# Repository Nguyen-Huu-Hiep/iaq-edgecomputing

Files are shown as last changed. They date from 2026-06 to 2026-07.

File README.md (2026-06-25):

# Hệ Thống Giám Sát Chất Lượng Không Khí Trong Nhà Dựa Trên Edge Computing

## Tổng Quan

Đề tài xây dựng hệ thống giám sát chất lượng không khí trong nhà (Indoor Air Quality - IAQ) dựa trên công nghệ Edge Computing và Internet of Things (IoT). Hệ thống sử dụng vi điều khiển ESP32 kết hợp với nhiều cảm biến môi trường để thu thập, xử lý và giám sát các thông số chất lượng không khí theo thời gian thực.

Khác với các hệ thống IoT truyền thống phụ thuộc hoàn toàn vào điện toán đám mây, hệ thống này thực hiện phần lớn quá trình xử lý dữ liệu ngay trên thiết bị biên (Edge Device). Các dữ liệu từ cảm biến được lọc nhiễu, phân tích và tính toán chỉ số chất lượng không khí (AQI) trước khi được gửi lên máy chủ để lưu trữ và trực quan hóa.

Hệ thống có khả năng giám sát liên tục các thông số như bụi mịn PM2.5, PM10, nồng độ CO₂, TVOC, nhiệt độ và độ ẩm. Chỉ số AQI được tính toán trực tiếp trên ESP32 theo tiêu chuẩn US EPA, giúp giảm độ trễ và đảm bảo khả năng cảnh báo kịp thời khi chất lượng không khí suy giảm.

---

## Chức Năng Chính

- Giám sát chất lượng không khí theo thời gian thực
- Đo nồng độ bụi PM2.5 và PM10
- Đo nồng độ khí CO₂
- Đo chỉ số TVOC
- Đo nhiệt độ và độ ẩm môi trường
- Tính toán chỉ số AQI tại thiết bị Edge
- Hiển thị dữ liệu trên màn hình TFT
- Lọc nhiễu bằng Median Filter và Kalman Filter
- Kết nối WiFi và tự động kết nối lại khi mất mạng
- Đồng bộ dữ liệu lên nền tảng Supabase
- Hỗ trợ cập nhật firmware OTA (Over-The-Air)
- Cảnh báo cục bộ khi chất lượng không khí vượt ngưỡng
- Cấu hình hệ thống thông qua giao diện Web

---

## Kiến Trúc Hệ Thống



## Phần Cứng Sử Dụng

- ESP32 Development Board
- Cảm biến bụi PMS5003/PMS7003
- Cảm biến CO₂ Sensirion SCD4x
- Cảm biến TVOC CCS811
- Màn hình TFT ST7789
- Hệ thống mạng WiFi

---

## Mô Hình Edge Computing

Hệ thống được thiết kế theo kiến trúc Edge Computing, trong đó ESP32 đóng vai trò là nút xử lý biên (Edge Node).

Các tác vụ được thực hiện trực tiếp trên ESP32 bao gồm:

- Thu thập dữ liệu cảm biến
- Kiểm tra tính hợp lệ của dữ liệu
- Lọc nhiễu tín hiệu
- Tính toán AQI
- Phát hiện trạng thái bất thường
- Kích hoạt cảnh báo cục bộ

Nhờ đó hệ thống mang lại các lợi ích:

- Giảm độ trễ xử lý
- Giảm lưu lượng truyền dữ liệu lên Cloud
- Giảm tải cho máy chủ
- Tăng tính ổn định khi mất kết nối Internet
- Đảm bảo khả năng cảnh báo theo thời gian thực

---

## Xử Lý Dữ Liệu

### Median Filter

Được sử dụng để loại bỏ các giá trị nhiễu đột biến từ cảm biến.

### Kalman Filter

Được sử dụng để làm mượt dữ liệu đo, tăng độ ổn định và độ tin cậy của kết quả.

### Tính Toán AQI

Chỉ số chất lượng không khí AQI được tính toán trực tiếp trên ESP32 dựa trên nồng độ PM2.5 theo tiêu chuẩn của Cơ quan Bảo vệ Môi trường Hoa Kỳ (US EPA).

---

## Kết Nối Đám Mây

Dữ liệu sau khi được xử lý tại Edge sẽ được gửi lên nền tảng Supabase thông qua giao thức HTTPS để:

- Lưu trữ lịch sử dữ liệu
- Phân tích xu hướng chất lượng không khí
- Hiển thị trên Dashboard giám sát
- Hỗ trợ truy cập từ xa

---

## Ứng Dụng

Hệ thống có thể được triển khai tại:

- Nhà ở thông minh (Smart Home)
- Lớp học
- Văn phòng
- Phòng thí nghiệm
- Bệnh viện
- Nhà xưởng sản xuất
- Các không gian kín cần giám sát chất lượng không khí

---

## Công Nghệ Sử Dụng

- ESP32
- Edge Computing
- Internet of Things (IoT)
- Supabase
- WiFi Manager
- OTA Firmware Update
- HTTP/HTTPS Communication
- AQI Calculation (US EPA Standard)

---

## Tác Giả

**Nguyễn Hữu Hiệp**

Ngành Kỹ thuật Tin học Công nghiệp

**Đồ án tốt nghiệp: Hệ thống giám sát chất lượng không khí trong nhà dựa trên Edge Computing và IoT**

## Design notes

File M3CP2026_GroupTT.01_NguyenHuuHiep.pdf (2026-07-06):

CAPSTONE PROJECT · CLASS 21PFIVEV2 · FAST – DUT

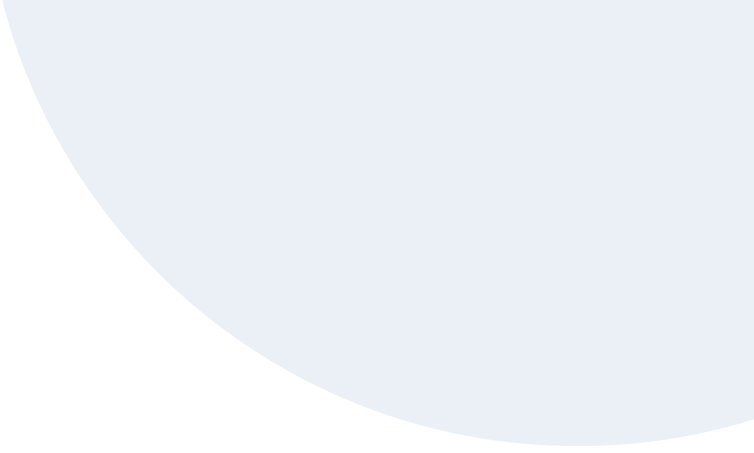
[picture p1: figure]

# DESIGN AND IMPLEMENTATION OF AN IOT-BASED INDOOR AIR QUALITY MONITORING SYSTEM FOR EDUCATIONAL ENVIRONMENTS

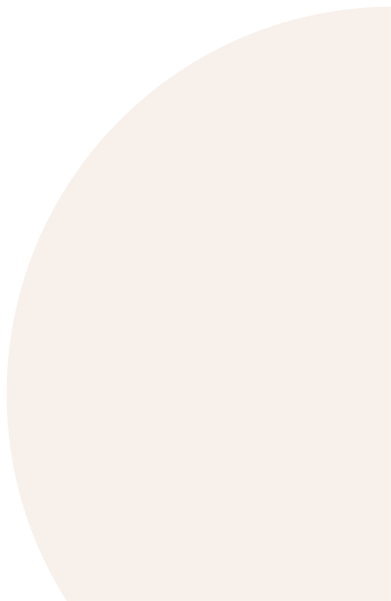
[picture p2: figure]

Students Tran Duong Xuan Anh · Nguyen Huu Hiep · Nguyen Minh Ngoc Huy

Supervisor Dr. Nguyen Le Hoa

Da Nang, June 2026

### AGENDA

# What We'll Cover

Experimental Results & Evaluation | 05 Conclusion & Future Directions

### 01 RESEARCH OVERVIEW

# Why is it necessary to monitor air quality in classrooms?

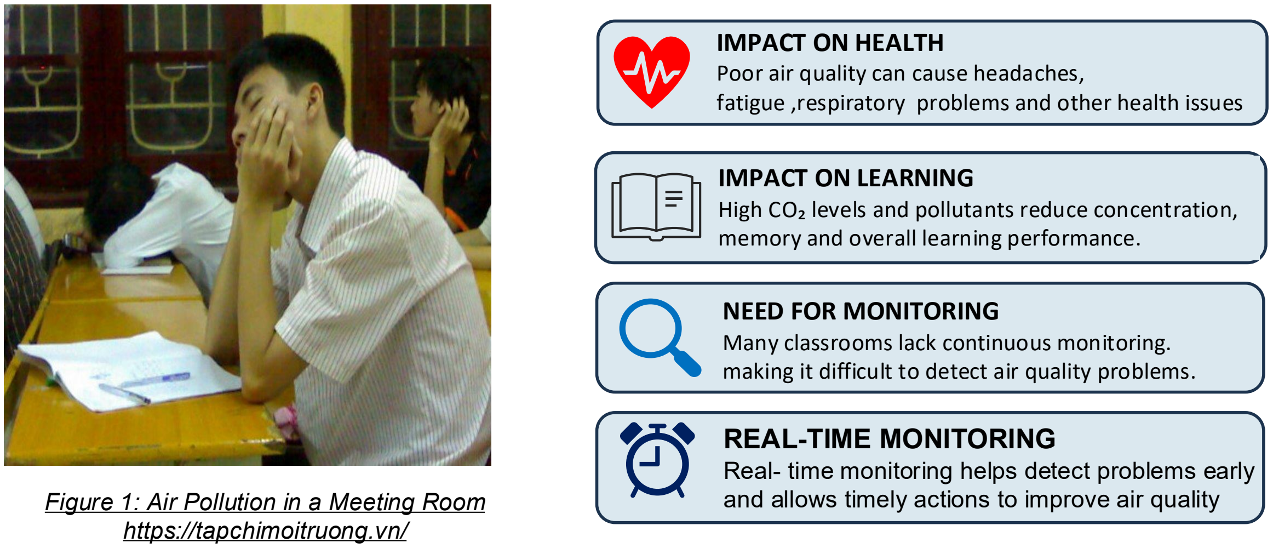
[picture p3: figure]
https://tapchimoitruong.vn/; REAL-TIME MONITORING; IMPACT ON HEALTH Poor air quality can cause headaches,; IMPACT ON LEARNING; memory and overall learning performance.; NEED FOR MONITORING Many classrooms lack continuous monitoring.

Figure 1: Air Pollution in a Meeting Room

Real- time monitoring helps detect problems early and allows timely actions to improve air quality fatigue ,respiratory problems and other health issues

High CO₂ levels and pollutants reduce concentration,

making it difficult to detect air quality problems.

### 01 RESEARCH OVERVIEW

## Research Objectives

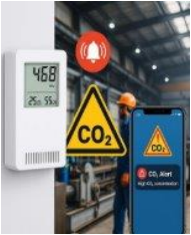
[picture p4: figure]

References [1] PM Decision 538/QĐ-TTg, 2021. [2] EVN Annual Report, 2023. [31] EVN Regulation 6074/EVN-KD, 2024. | 4 / 24

### Design a smart air quality monitoring system for classrooms

### Real-time IAQ monitoring

### Early warning when CO₂ and PM2.5 exceed safety thresholds

### Provide data for trend analysis

### All collected data are uploaded to a cloud dashboard

### Support classroom environment management

### Increase awareness among students and teachers

Figure 2: Threshold Exceedance Warning (https://ubibot.vn/wp-content/uploads/2025/06/thiet-bi-canh-bao-nong-do-co2.jpg)

### 01 RESEARCH OVERVIEW

# Overview of indoor air quality in classrooms

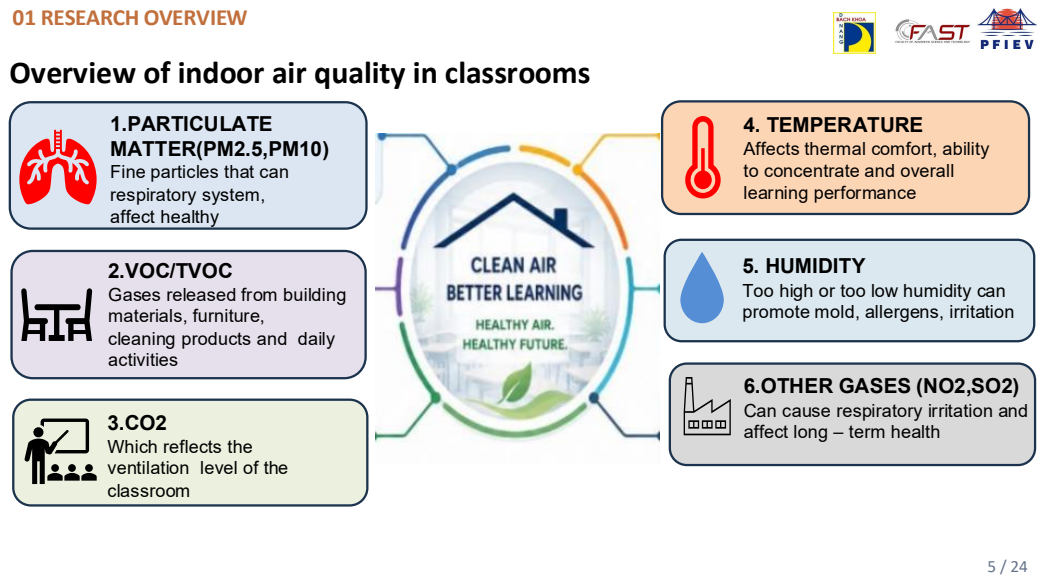
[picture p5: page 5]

1.PARTICULATE
MATTER(PM2.5,PM10)
Fine particles that can
respiratory system,
affect healthy

4. TEMPERATURE
Affects thermal comfort, ability
to concentrate and overall
learning performance

2.VOC/TVOC
Gases released from building
materials, furniture,
cleaning products and daily
activities

5. HUMIDITY
Too high or too low humidity can
promote mold, allergens, irritation

6.OTHER GASES (NO2,SO2)
Can cause respiratory irritation and
affect long – term health

Which reflects the
ventilation level of the
classroom

### 01 RESEARCH OVERVIEW

# Commercial product

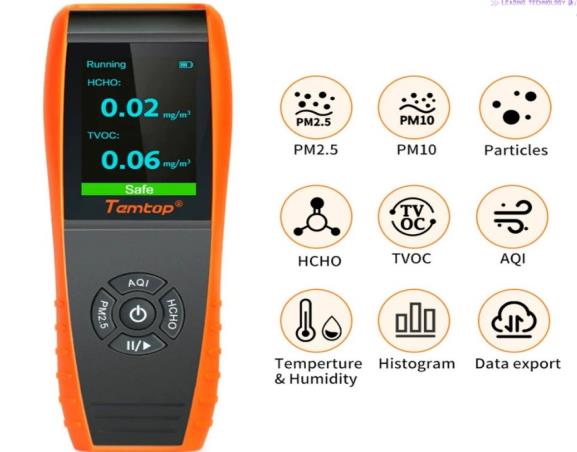
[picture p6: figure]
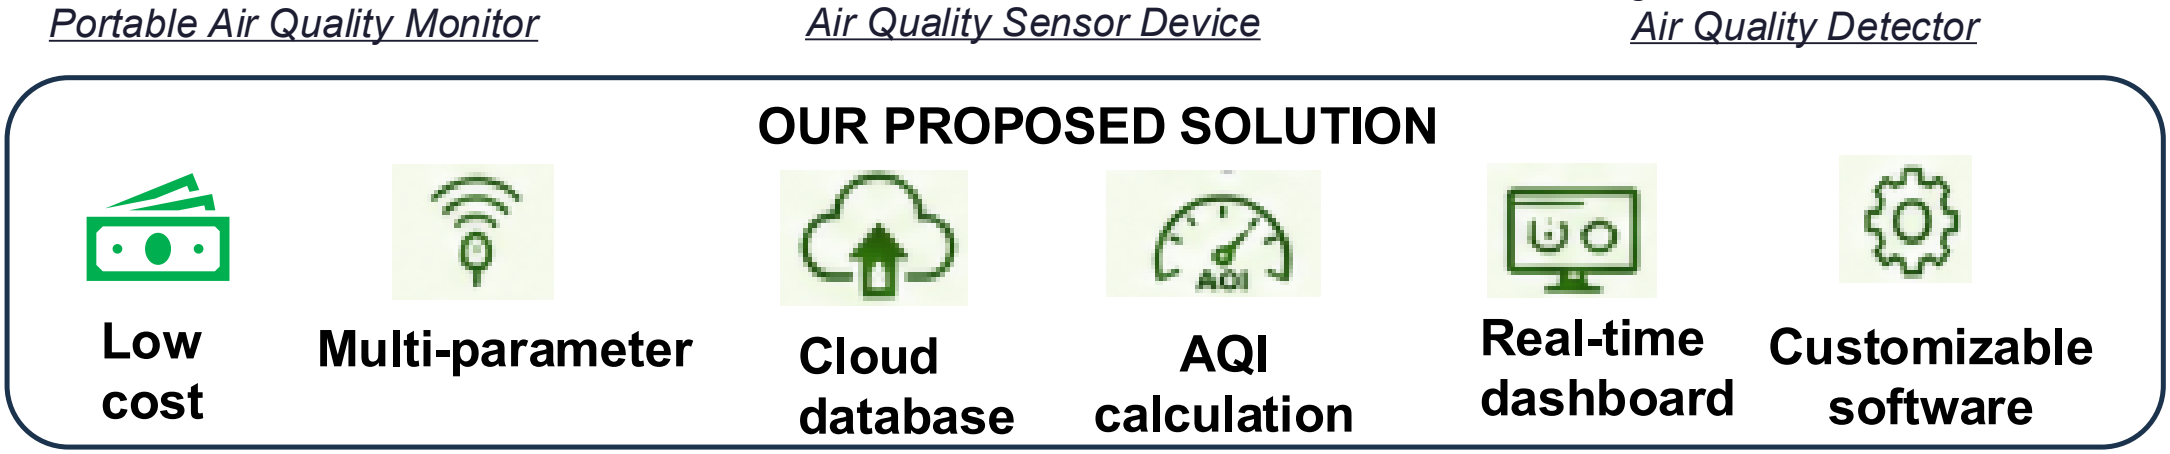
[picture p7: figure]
Portable Air Quality Monitor; Air Quality Sensor Device; Air Quality Detector; OUR PROPOSED SOLUTION; Low cost; Multi-parameter; AQI; calculation; Real-time dashboard; Customizable software; Cloud database

Figure (https://dientuthaithang.com/may-do-chat-luong-khong-khi-7-in-1-temtop-lkc-1000s-3161-357.html) 3 (https://dientuthaithang.com/may-do-chat-luong-khong-khi-7-in-1-temtop-lkc-1000s-3161-357.html): Temtop LKC (https://dientuthaithang.com/may-do-chat-luong-khong-khi-7-in-1-temtop-lkc-1000s-3161-357.html)- (https://dientuthaithang.com/may-do-chat-luong-khong-khi-7-in-1-temtop-lkc-1000s-3161-357.html)1000 (https://dientuthaithang.com/may-do-chat-luong-khong-khi-7-in-1-temtop-lkc-1000s-3161-357.html)S

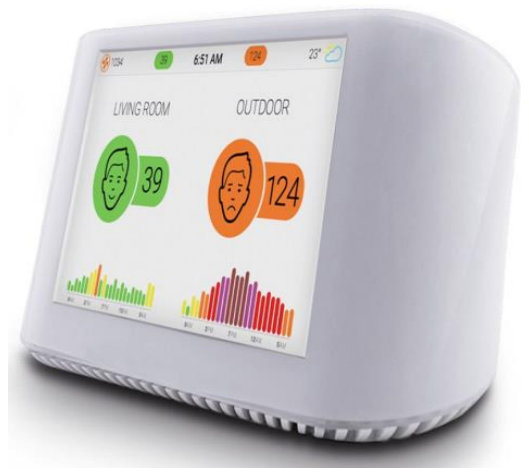
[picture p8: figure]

Figure (https://www.iqair.com/vi/products/air-quality-monitors/airvisual-pro-indoor-monitor) 4 (https://www.iqair.com/vi/products/air-quality-monitors/airvisual-pro-indoor-monitor): IQAir AirVisual Pro

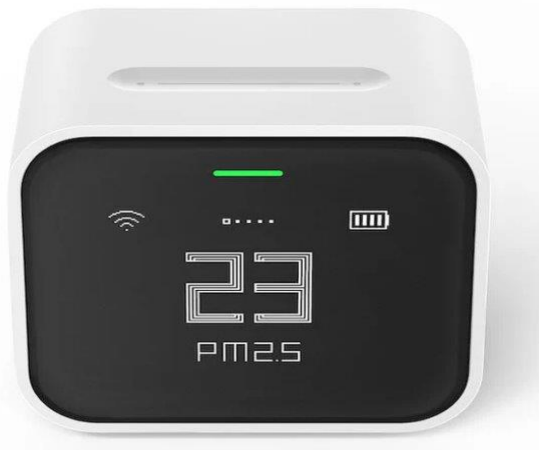
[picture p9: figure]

Figure (https://miworld.vn/thiet-bi-cho-suc-khoe/may-do-chat-luong-khong-khi-xiaomi-pm2-5-air-quality-detector-p11700.html) 5 (https://miworld.vn/thiet-bi-cho-suc-khoe/may-do-chat-luong-khong-khi-xiaomi-pm2-5-air-quality-detector-p11700.html): Xiaomi PM2.5

### 2.THEORETICAL BASIS AND STANDARDS

## General Introduction to Air Quality Standards

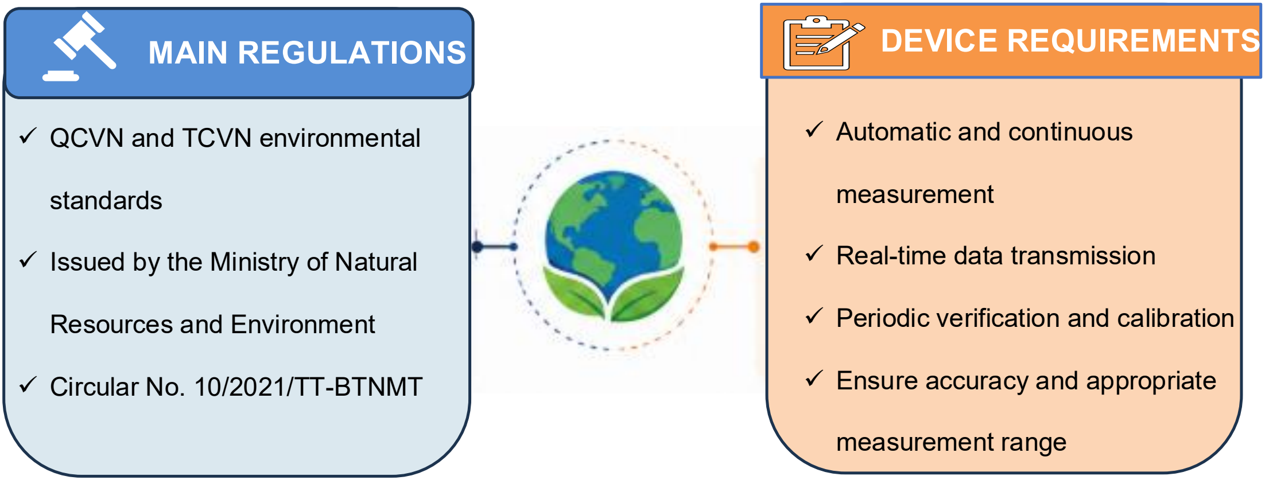
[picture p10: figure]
MAIN REGULATIONS; ✓ QCVN and TCVN environmental; standards; ✓ Issued by the Ministry of Natural; Resources and Environment; ✓ Circular No. 10/2021/TT-BTNMT; DEVICE REQUIREMENTS; ✓ Automatic and continuous; measurement; ✓ Real-time data transmission; ✓ Periodic verification and calibration; ✓ Ensure accuracy and appropriate; measurement range

### 2.THEORETICAL BASIS AND STANDARDS

## Pollution Level Classification According to IAQ

IAQ Range | Pollution Level | Display Color | Health Impact
0 – 50 | Good | Green | No health effects
51 – 100 | Moderate | Yellow | May cause minor effects for sensitive individuals
101 – 150 | Unhealthy for Sensitive Groups | Orange | Affects sensitive groups(elderly, children)
151 – 200 | Unhealthy | Red | Affects everyone’s health
201 – 300 | Very Unhealthy | Purple | Serious health effects
> 300 | Hazardous | Maroon | Emergency health warning

Table 2: Air Quality Assessment Levels

### 2.THEORETICAL BASIS AND STANDARDS

# Technical specification requirements

Table 3: Required Technical Specifications for Measured Parameters

No | Measurement Parameter | Unit | Accuracy(% of range) | Measurement Range | Resolution | Response Time
1 | Temperature | °C | ±5% | 0 ÷ 80 | 0,1 | ≤ 120 seconds
2 | PM2.5 dust | µg/m³ | ±5% | 0 ÷ 250 | 0,1 | ≤ 60 seconds
3 | PM10 dust | µg/m³ | ±3% | 0 ÷ 500 | 0.1 | ≤ 60 seconds
4 | CO2 | ppm | ±5% | 0 ÷ 5.000 | 1 | ≤ 120 seconds
5 | TVOC | µg/m³ | ±10% | 0 ÷ 2.000 | 1 | ≤ 60 seconds

Ensures accuracy and
reliability of measurement

Meets national standards
for IAQ monitoring

Real-time response for
timely alerts and actions

### 03 · SYSTEM DESIGN

# Overall System Architecture

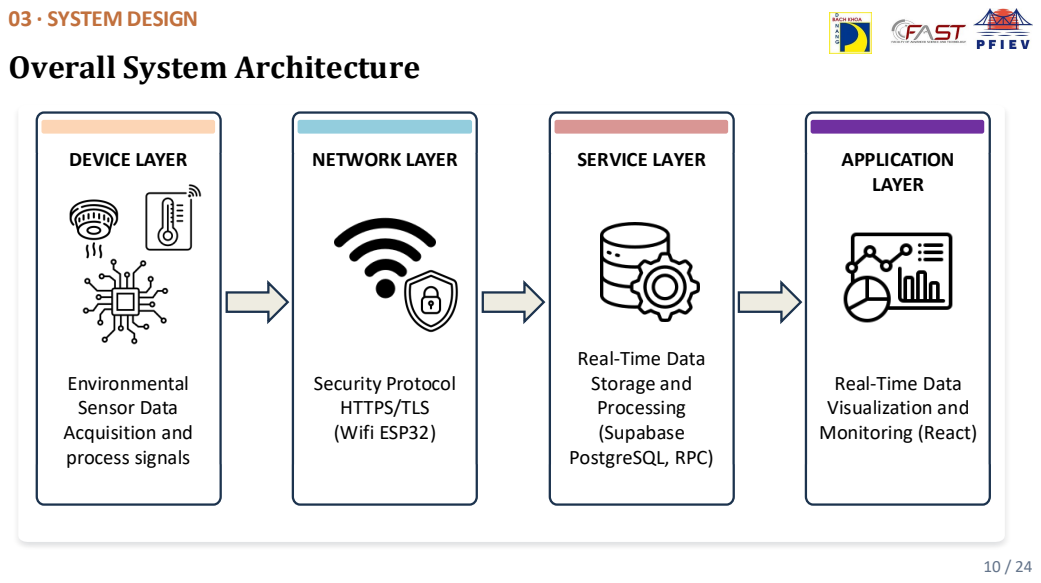
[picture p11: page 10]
DEVICE LAYER; Environmental Sensor Data Acquisition and process signals; NETWORK LAYER; Security Protocol HTTPS/TLS (Wifi ESP32); SERVICE LAYER; APPLICATION LAYER

Real-Time Data
Storage and
Processing
(Supabase
PostgreSQL, RPC)

Visualization and
Monitoring (React)

### 03 · SYSTEM DESIGN

# Hardware Block Diagram & Circuit Schematic

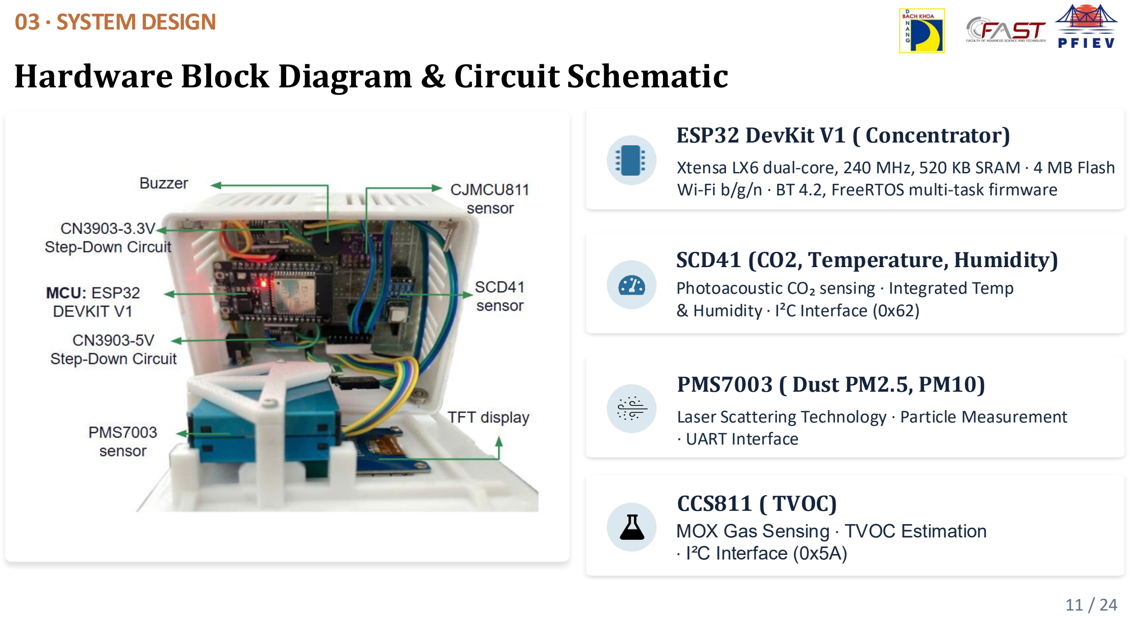
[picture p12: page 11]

ESP32 DevKit V1 ( Concentrator)

Xtensa LX6 dual-core, 240 MHz, 520 KB SRAM · 4 MB Flash Wi-Fi b/g/n · BT 4.2, FreeRTOS multi-task firmware

SCD41 (CO2, Temperature, Humidity)

PMS7003 ( Dust PM2.5, PM10)

CCS811 ( TVOC)

Photoacoustic CO₂ sensing · Integrated Temp
& Humidity · I²C Interface (0x62)

Laser Scattering Technology · Particle Measurement
- UART Interface

MOX Gas Sensing · TVOC Estimation
- I²C Interface (0x5A)

### 03 · SYSTEM DESIGN

# Multitasking with FreeRTOS on a Dual-Core Architecture

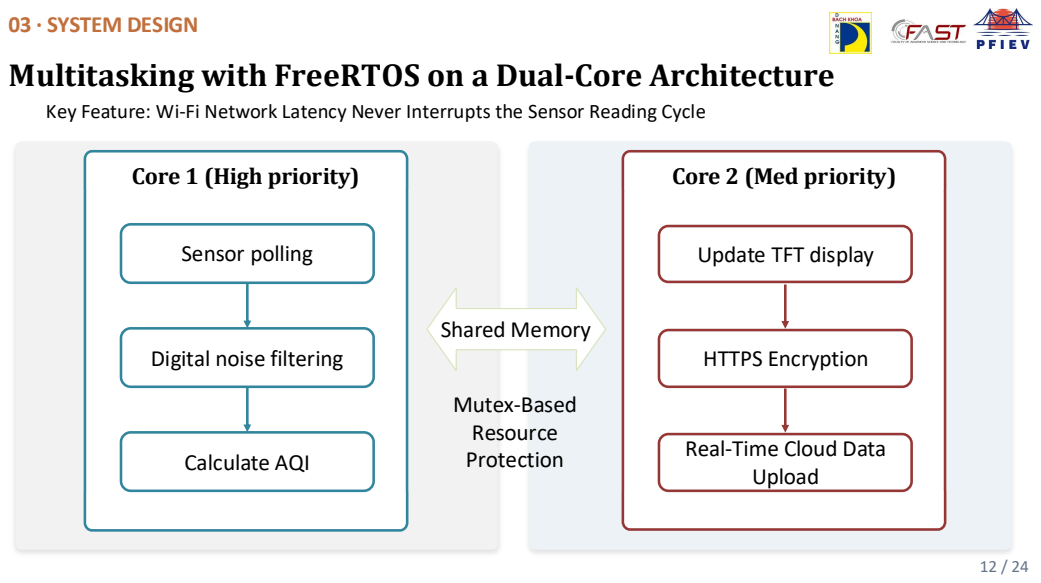
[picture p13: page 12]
Sensor polling; Calculate AQI; HTTPS Encryption; Shared Memory; Mutex-Based Resource Protection

Key Feature: Wi-Fi Network Latency Never Interrupts the Sensor Reading Cycle

Core 1 (High priority)

Core 2 (Med priority)

Update TFT display

Digital noise filtering

Real-Time Cloud Data
Upload

### 03 · SYSTEM DESIGN

# Signal Processing Pipeline

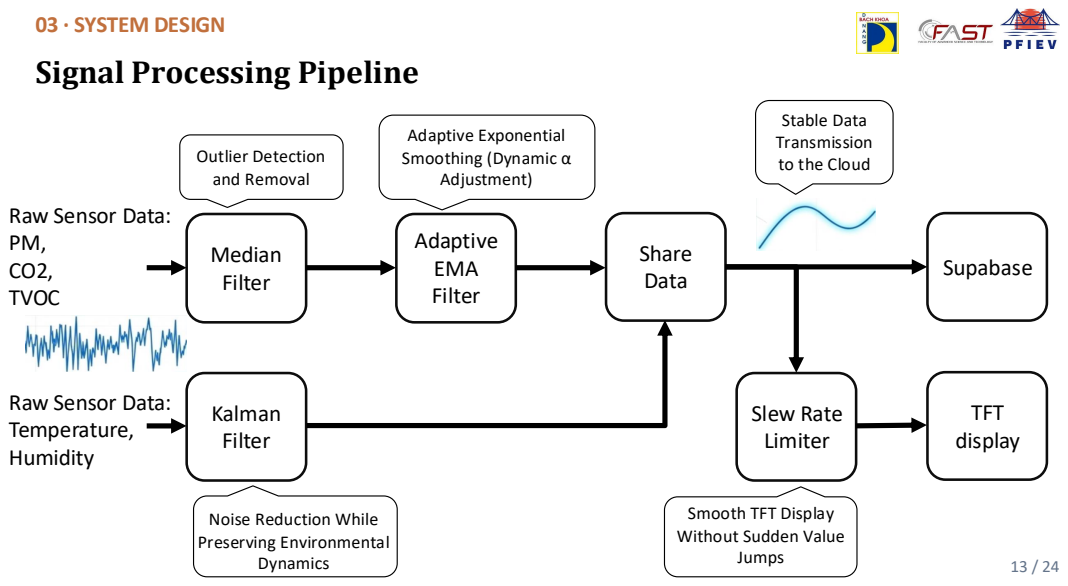
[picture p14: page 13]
Median Filter; Kalman Filter; Adaptive EMA Filter; Share; Data; Supabase; Slew Rate Limiter; TFT display; Raw Sensor Data: PM, CO2, TVOC; Adaptive Exponential Smoothing (Dynamic α Adjustment); Outlier Detection and Removal; Dynamics; Jumps

Stable Data
Transmission
to the Cloud

Raw Sensor Data:
Temperature,
Humidity

Noise Reduction While
Preserving Environmental

Smooth TFT Display
Without Sudden Value

### 03 · SYSTEM DESIGN

# Cloud Storage Architecture (Supabase/PostgreSQL)

### JSON Payload from the Edge Device (Edge Payload)

### RPC Stored Procedure (upsert_iaq)

### Table aqi_room

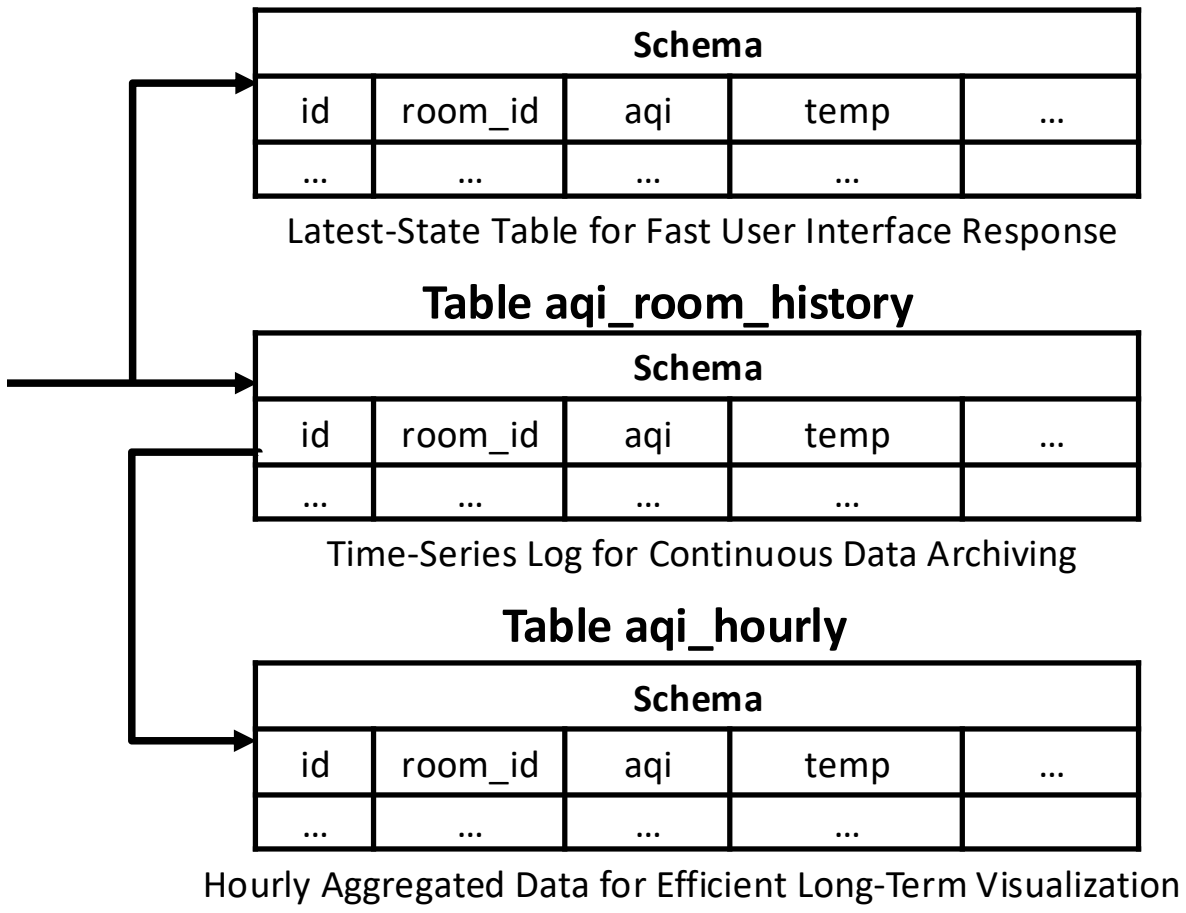
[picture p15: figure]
Table aqi_room_history; Table aqi_hourly; Schema; room_id; aqi; temp

Latest-State Table for Fast User Interface Response

Time-Series Log for Continuous Data Archiving

Hourly Aggregated Data for Efficient Long-Term Visualization

Atomic Operations at the
Database Layer to Eliminate Network Bottlenecks

### 03 · SYSTEM DESIGN

# Web Monitoring Interface

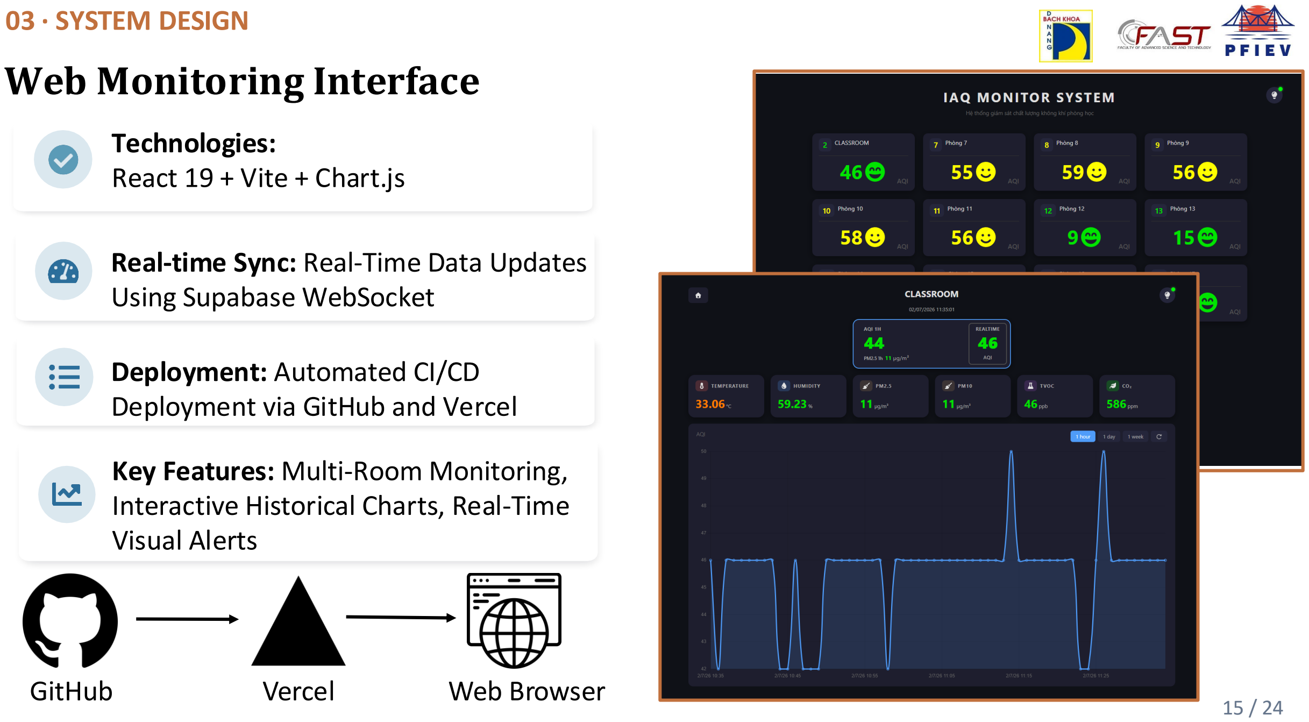
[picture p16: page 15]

### Technologies: React 19 + Vite + Chart.js

### Real-time Sync: Real-Time Data Updates Using Supabase WebSocket

### Deployment: Automated CI/CD Deployment via GitHub and Vercel

Key Features: Multi-Room Monitoring,

### Interactive Historical Charts, Real-Time Visual Alerts

GitHub | Vercel | Web Browser

### 03 · SYSTEM DESIGN

# Wi-Fi Captive Portal & update OTA

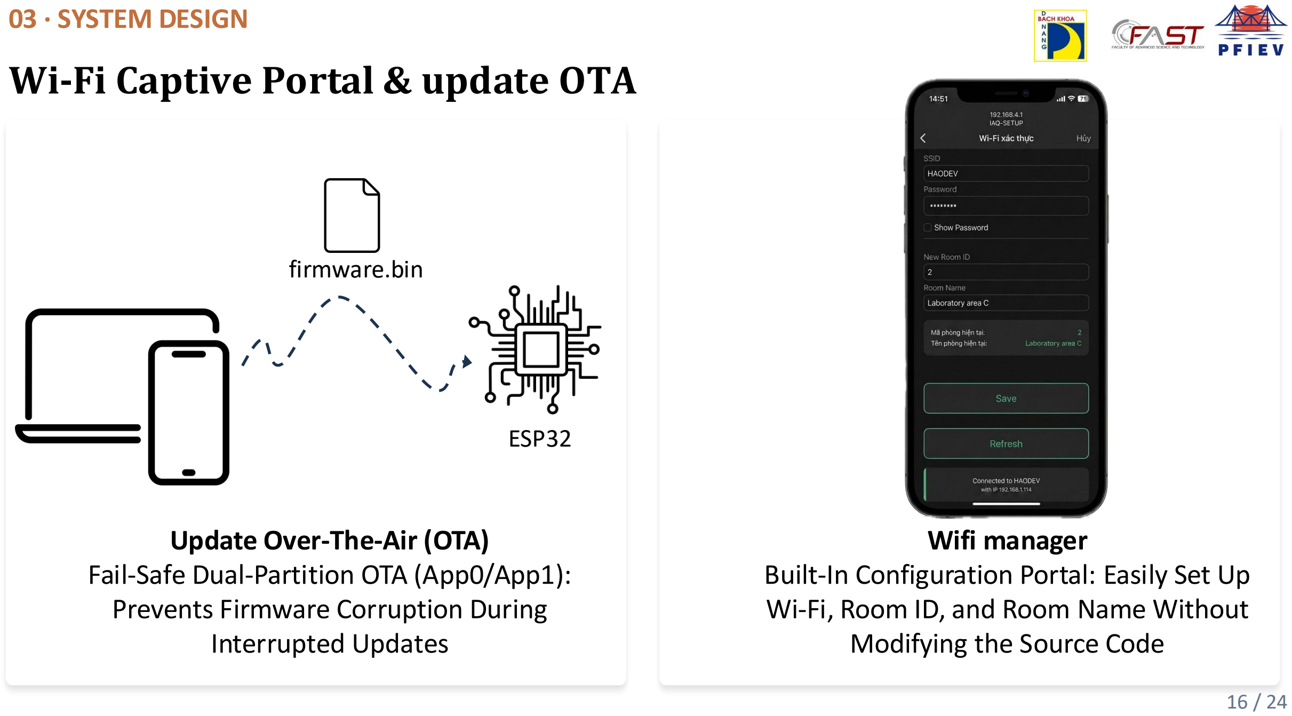
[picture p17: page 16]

### Wifi manager Built-In Configuration Portal: Easily Set Up Wi-Fi, Room ID, and Room Name Without Modifying the Source Code

firmware.bin

ESP32

### Update Over-The-Air (OTA) Fail-Safe Dual-Partition OTA (App0/App1): Prevents Firmware Corruption During Interrupted Updates

### 4 · EXPERIMENTATION AND EVALUATION OF SYSTEM RESULTS

# Experimental Environment and Configuration

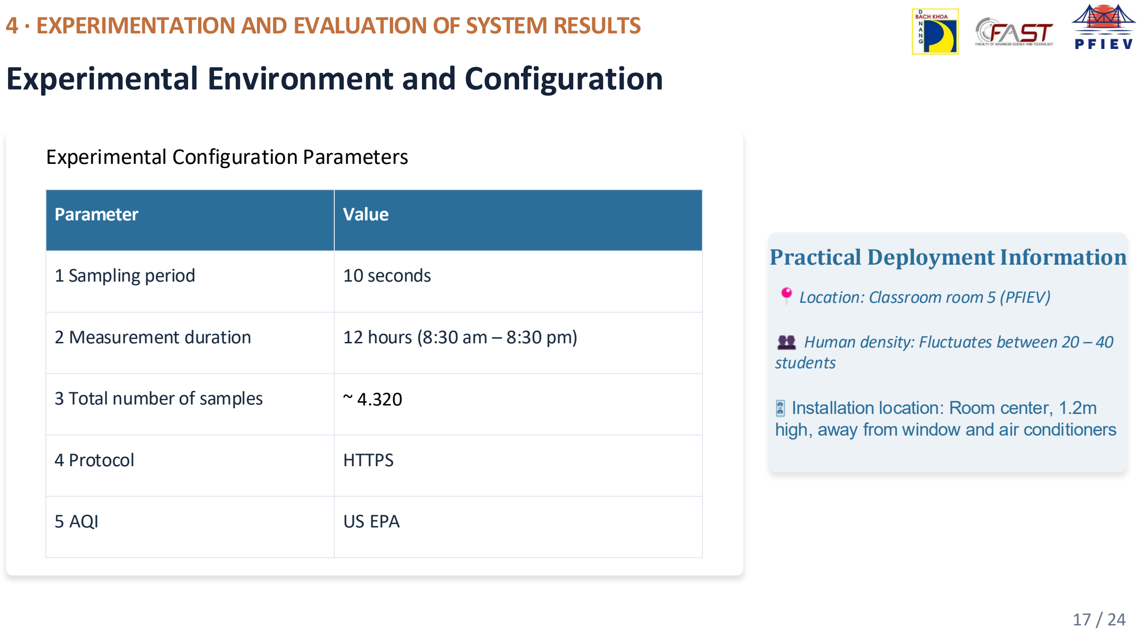
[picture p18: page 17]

Parameter | Value
1 Sampling period | 10 seconds
2 Measurement duration | 12 hours (8:30 am – 8:30 pm)
3 Total number of samples | ~ 4.320
4 Protocol | HTTPS
5 AQI | US EPA

Practical Deployment Information

Location: Classroom room 5 (PFIEV)

Human density: Fluctuates between 20 – 40 students

Installation location: Room center, 1.2m high, away from window and air conditioners

Experimental Configuration Parameters

### 4 · EXPERIMENTATION AND EVALUATION OF SYSTEM RESULTS

# Evaluation of Operational Capability

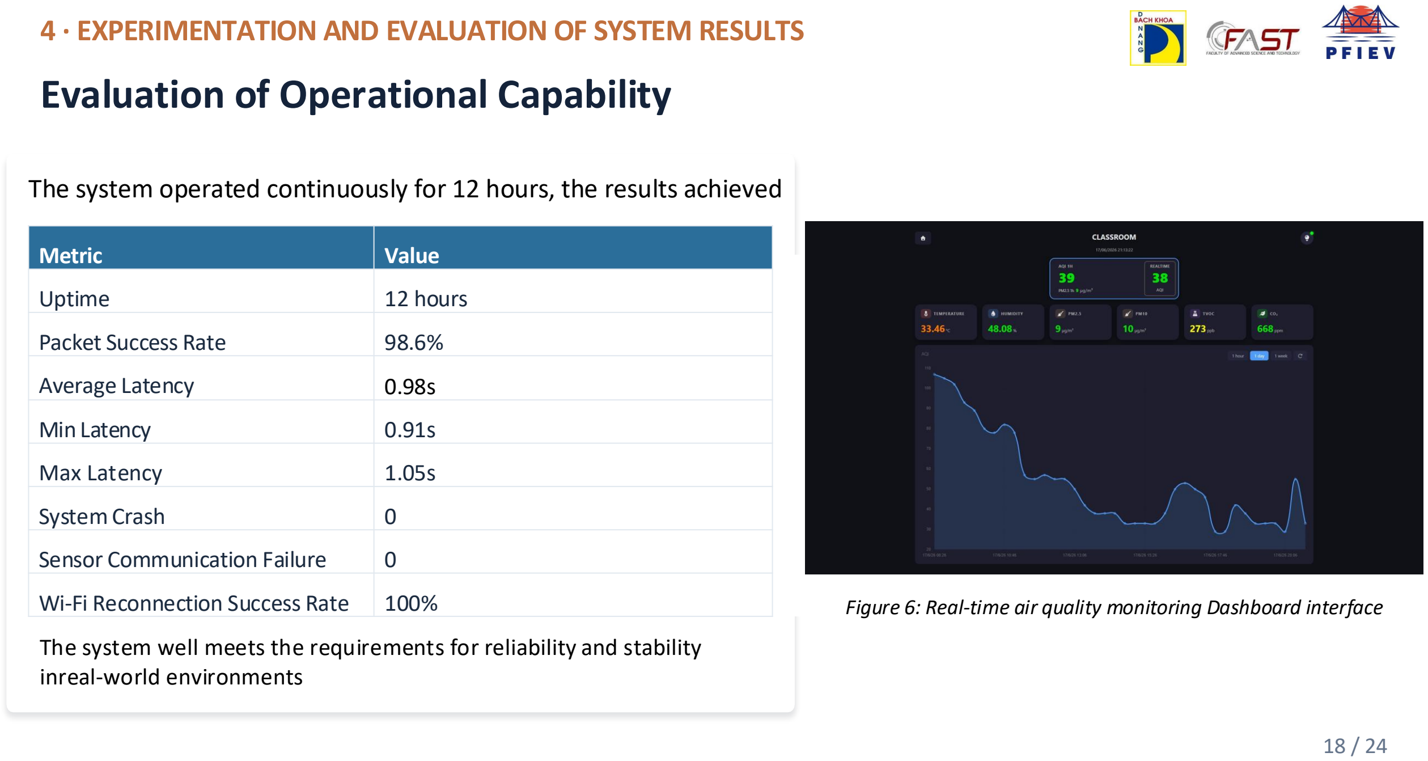
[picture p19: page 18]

Metric | Value
Uptime | | 12 hours
Packet Success Rate | | 98.6%
Average Latency | | 0.98s
Min Latency | | 0.91s
Max Latency | | 1.05s
System Crash | | 0
Sensor Communication Failure | | 0
Wi-Fi Reconnection Success Rate | | 100%

The system operated continuously for 12 hours, the results achieved

The system well meets the requirements for reliability and stability inreal-world environments

Figure 6: Real-time air quality monitoring Dashboard interface

### 4 · EXPERIMENTATION AND EVALUATION OF SYSTEM RESULTS

# Evaluation of System Sensor Errors

Measurement Parameter | MAE Index | MAPE Index | Quality Evaluation | Conclusion
Temperature | 0.95 °C | 2.85% | Extremely small error, completely tracking the national standard measurement device | Very high
PM2.5 | 1.19 µg/m³ | 8.31% | Lies below the 10% error threshold, extremely accurately reflecting the variation of fine dust concentration | Good
PM10 | 24.59 µg/m³ | 53.49% | Fairly high error, measured values are always lower than reality by about 2 times. Due to large dust particles easily settling and the influence of airflow structure | Average (Recalibration needed)
Humidity | 7.43%RH | 12.51% | Tends to measure 8-10% lower than the standard in high humidity ranges, but still ensures high stability | Stable

Table 4: Accuracy evaluation compared to the reference monitoring station

### 4 · EXPERIMENTATION AND EVALUATION OF SYSTEM RESULTS

# Actual CO₂ & TVOC Fluctuations

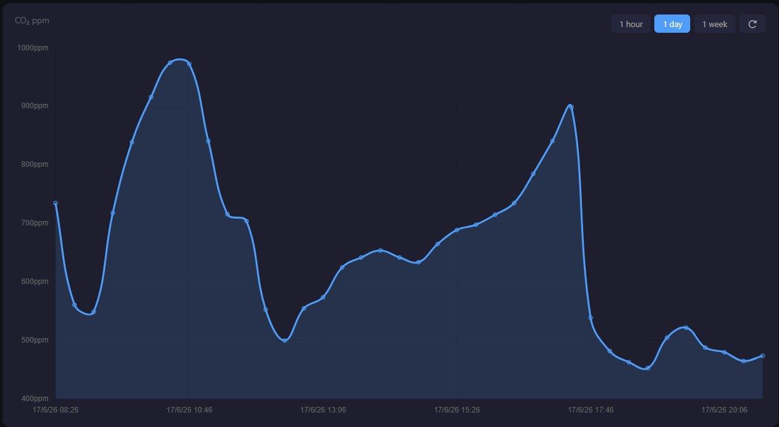
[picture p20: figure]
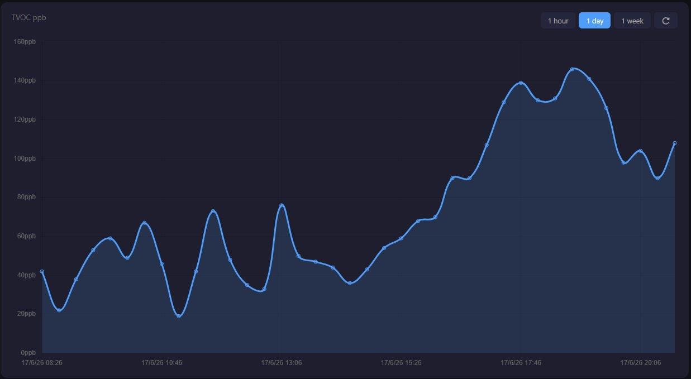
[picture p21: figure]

Figure 7: CO₂ concentration variation over time | Figure 8: TVOC concentration variation over time
CO₂ Carbon Dioxide Gas
- Fluctuated most strongly according to human behavior and
student density, peaking at 900 - 1000 ppm during peak class
hours
- Decreased rapidly to a stable range of 450 - 550 ppm when opening doors for ventilation or after class dismissed, reflecting the effectiveness of natural ventilation | TVOC Organic Compounds • Fluctuated within the range of 20 - 150 ppb. Accumulated with a delay and surged suddenly to peak at the end of the measurement session. • Continuously generated from the plywood adhesive of tables and chairs, classroom cleaning activities, and heat dissipated from computer devices.

### 4 · EXPERIMENTATION AND EVALUATION OF SYSTEM RESULTS

# Actual PM2.5 & AQI Fluctuations

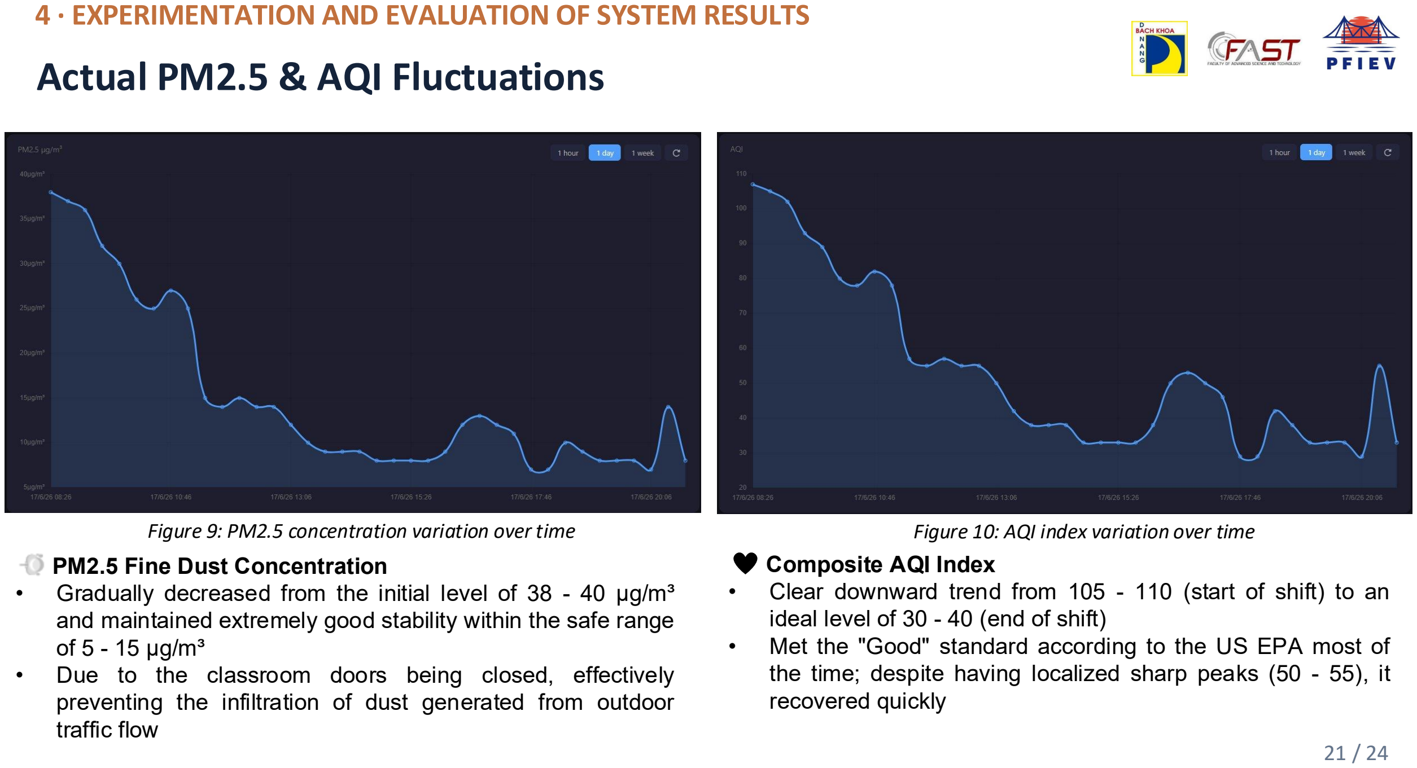
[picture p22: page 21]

Figure 9: PM2.5 concentration variation over time | Figure 10: AQI index variation over time
PM2.5 Fine Dust Concentration • Gradually decreased from the initial level of 38 - 40 µg/m³ and maintained extremely good stability within the safe range of 5 - 15 µg/m³ • Due to the classroom doors being closed, effectively preventing the infiltration of dust generated from outdoor traffic flow | Composite AQI Index • Clear downward trend from 105 - 110 (start of shift) to an ideal level of 30 - 40 (end of shift) • Met the "Good" standard according to the US EPA most of the time; despite having localized sharp peaks (50 - 55), it recovered quickly

### 5· CONCLUSION AND FUTURE DIRECTIONS

# General Conclusion

Objectives

Successfully completed the design and fabrication of the IoT-based multi-parameter monitoring system, perfectly matching all initial project specifications.

Technical

Effectively integrated ESP32 microcontrollers, Supabase cloud databases, and specialized precision sensors to achieve stable, high-accuracy data ingestion.

Academic

Rigorously validated system error rates (MAE, MAPE) against certified standards, establishing acceptable precision thresholds for civilian air monitoring.

Practicality

Developed a highly viable, cost-optimized solution readily deployable across smart classrooms and next-generation green school environments.

### 5· CONCLUSION AND FUTURE DIRECTIONS

# Future Development Directions

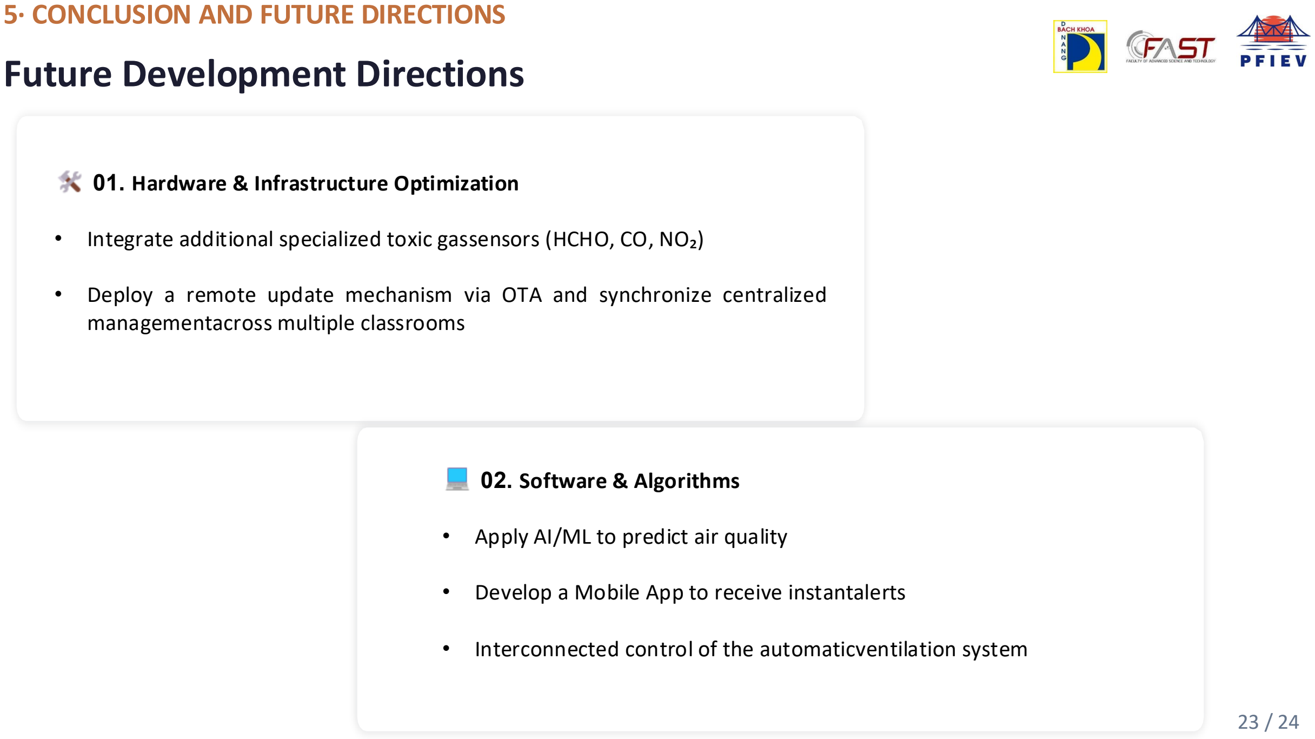
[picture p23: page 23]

### 01. Hardware & Infrastructure Optimization

- Integrate additional specialized toxic gassensors (HCHO, CO, NO₂)
- Deploy a remote update mechanism via OTA and synchronize centralized managementacross multiple classrooms

### 02. Software & Algorithms

- Apply AI/ML to predict air quality
- Develop a Mobile App to receive instantalerts
- Interconnected control of the automaticventilation system

# THANK YOU FOR LISTENING

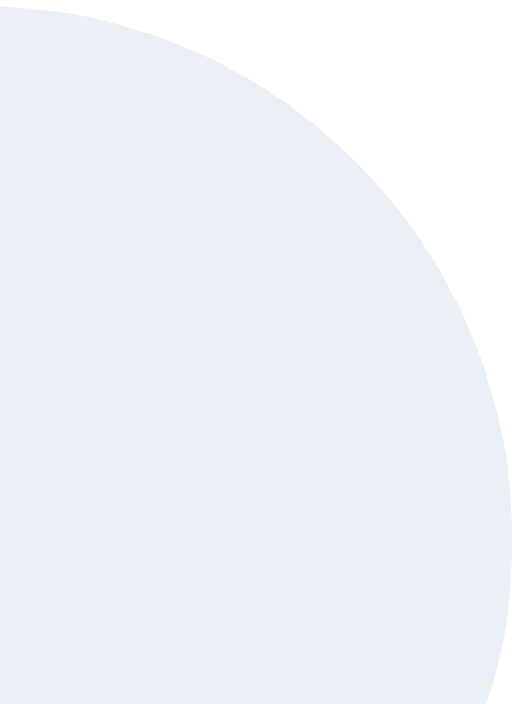
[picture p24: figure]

Q & A

Tran Duong Xuan Anh · Nguyen Huu Hiep · Nguyen Minh Ngoc Huy Group TT.01 · Class 21PFIEV2 · FAST – Da Nang University of Technology

Supervisor: Dr. Nguyen Le Hoa

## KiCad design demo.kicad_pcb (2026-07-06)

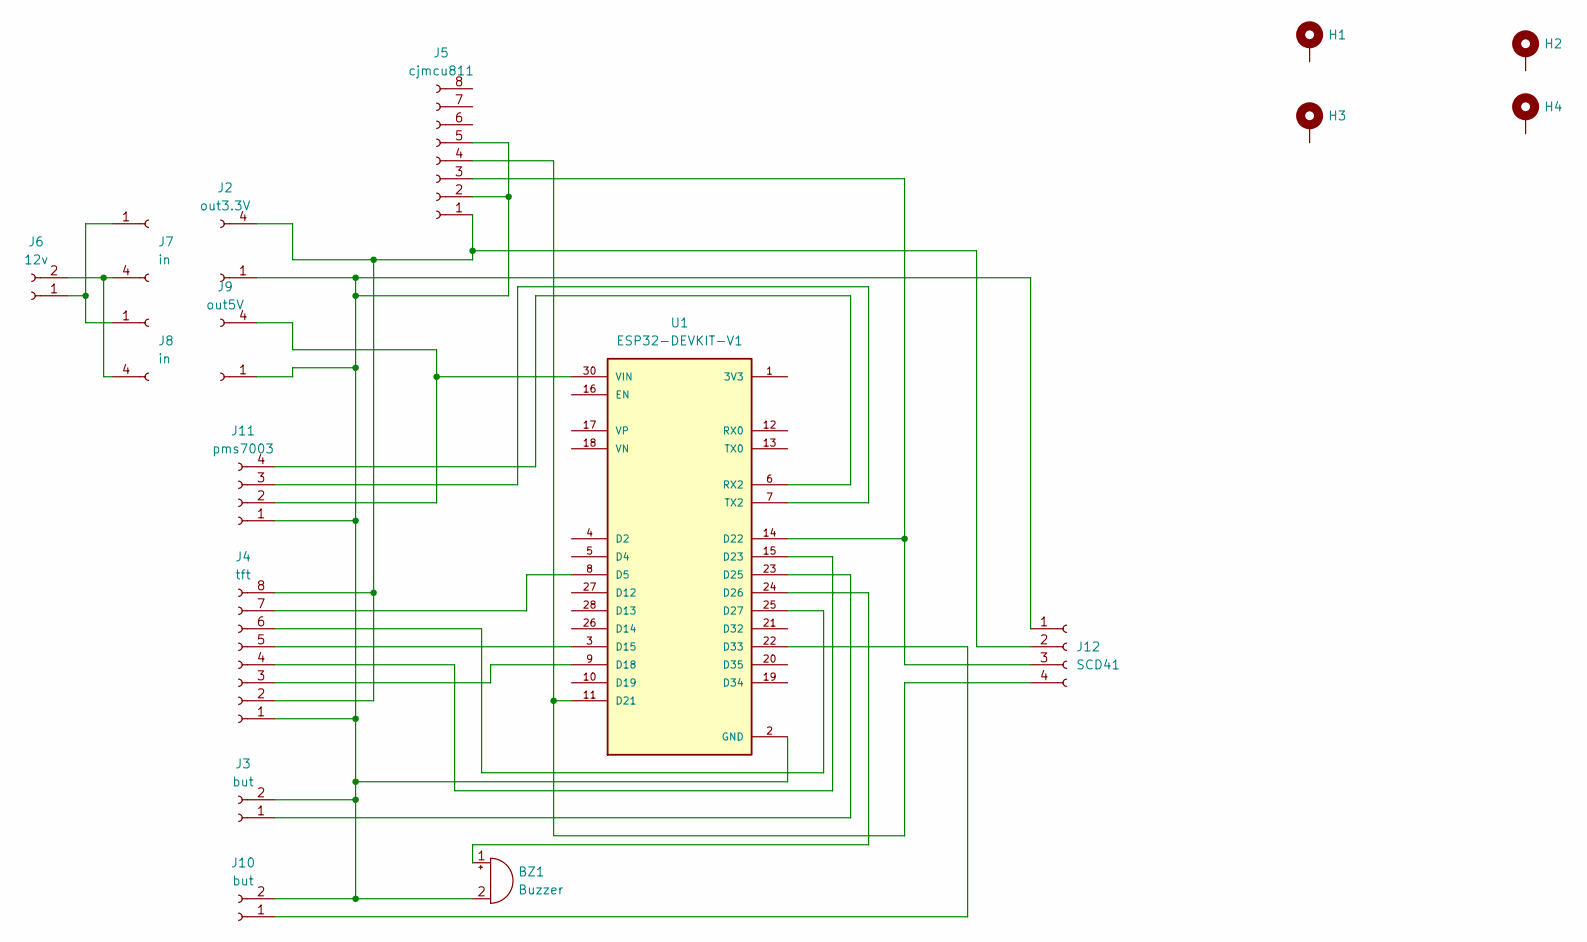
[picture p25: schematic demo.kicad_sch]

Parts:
BZ1: Buzzer; Buzzer_12x9.5RM7.6
H1, H2, H3, H4: MountingHole_Pad; MountingHole_2.2mm_M2_Pad_Via
J2: out3.3V; PinSocket_1x04_P2.54mm_Vertical
J3, J10: but; JST_PH_B2B-PH-K_1x02_P2.00mm_Vertical
J4: tft; JST_PH_B8B-PH-K_1x08_P2.00mm_Vertical
J5: cjmcu811; PinSocket_1x08_P2.54mm_Vertical
J6: 12v; JST_PH_B2B-PH-K_1x02_P2.00mm_Vertical
J7, J8: in; PinSocket_1x04_P2.54mm_Vertical
J9: out5V; PinSocket_1x04_P2.54mm_Vertical
J11: pms7003; JST_PH_B4B-PH-K_1x04_P2.00mm_Vertical
J12: SCD41; PinSocket_1x04_P2.54mm_Vertical
U1: ESP32-DEVKIT-V1; MODULE_ESP32_DEVKIT_V1; PARTREV N/A

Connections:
GND: BZ1.2 (-), J2.1, J3.2, J4.1, J5.2, J5.5, J9.1, J10.2, J11.1, J12.1, U1.2 (GND), U1.29 (GND)
unnamed: BZ1.1 (+), U1.24 (D26)
unnamed: J3.1, U1.23 (D25)
unnamed: J4.3, U1.9 (D18)
unnamed: J4.4, U1.15 (D23)
unnamed: J4.5, U1.3 (D15)
unnamed: J4.6, U1.25 (D27)
unnamed: J4.7, U1.8 (D5)
unnamed: J6.1, J7.1, J8.1
unnamed: J6.2, J7.4, J8.4
unnamed: J10.1, U1.22 (D33)
unnamed: J9.4, J11.2, U1.30 (VIN)
unnamed: J11.3, U1.7 (TX2)
unnamed: J11.4, U1.6 (RX2)
unnamed: J2.4, J4.2, J4.8, J5.1, J12.2
unnamed: J5.3, J12.3, U1.14 (D22)
unnamed: J5.4, J12.4, U1.11 (D21)

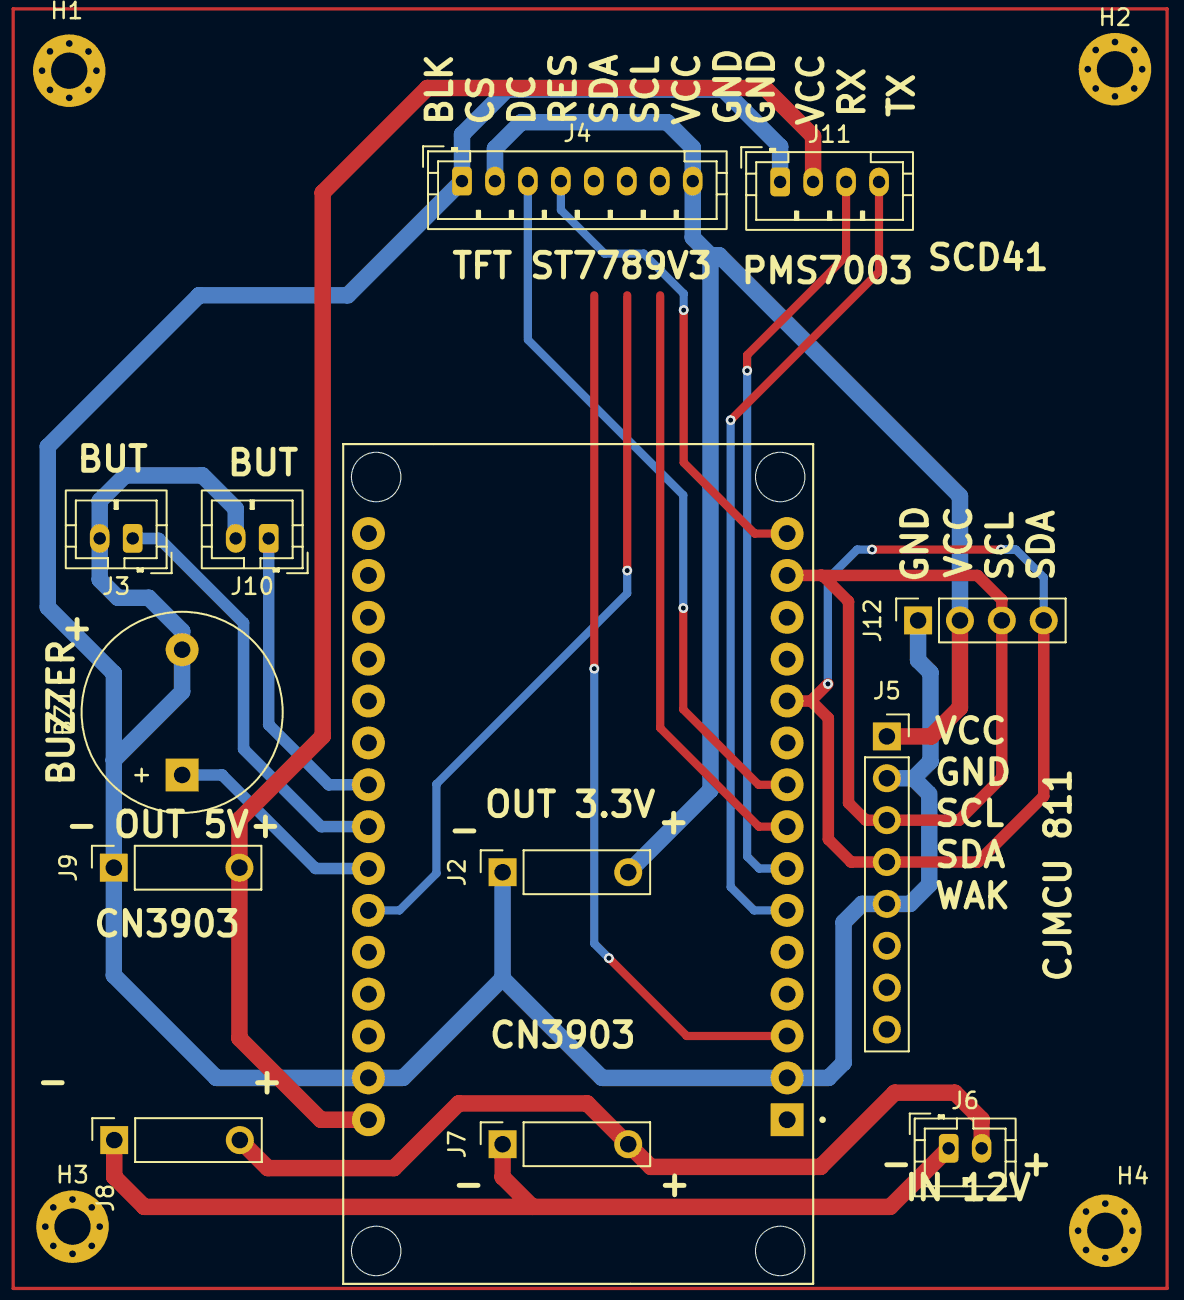
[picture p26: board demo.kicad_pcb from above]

Board: 2 copper layers, 17 parts (0 on the bottom side), 17 nets.

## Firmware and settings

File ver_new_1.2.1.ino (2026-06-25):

#include <Wire.h>
#include <Adafruit_GFX.h>
#include <WiFi.h>
#include <WiFiClientSecure.h>
#include <HTTPClient.h>
#include "Adafruit_CCS811.h"
#include <Arduino_GFX_Library.h>
#include "FreeSans9pt7b.h"
#include <WiFiManager.h>
#include <Preferences.h>
#include <SensirionI2cScd4x.h> 

// Thư viện mạng phục vụ Web Server & OTA nâng cao
#include <WebServer.h>
#include <ESPmDNS.h>
#include <ElegantOTA.h>

// ====================== ĐỊNH NGHĨA PHIÊN BẢN FIMWARE ======================
#define FIRMWARE_VERSION    "1.2.1"

// ====================== CẤU HÌNH PHẦN CỨNG ======================
#define ERROR_LED       2 
#define RXD2            16
#define TXD2            17
#define CONFIG_BUTTON   25
#define BUZZER_PIN      26

#define TFT_SCL         18
#define TFT_SDA         23
#define TFT_RES         15
#define TFT_DC          27
#define TFT_CS          5

const char* url = "https://ijfgklxwtacolgevxred.supabase.co/rest/v1/rpc/upsert_iaq";
const char* apiKey = "sb_publishable_bc8gAWEKPCo5roEWMVCDAA_1eWtB2F-";

// ====================== KHỞI TẠO ĐỐI TƯỢNG ======================
Preferences prefs;
char roomId[6] = "0";
char roomName[50] = "Unknown";

SensirionI2cScd4x scd4x;
Adafruit_CCS811 ccs;
Arduino_DataBus *bus = new Arduino_ESP32SPI(TFT_DC, TFT_CS, TFT_SCL, TFT_SDA, -1);
Arduino_GFX *tft = new Arduino_ST7789(bus, TFT_RES, 1, true, 240, 280, 0, 20, 0, 20);

WiFiManager wm;
WiFiManagerParameter custom_room("room", "New Room ID", "", 5);
WiFiManagerParameter custom_room_name( "roomname", "Room Name", "",50);

WebServer server(80);
bool isServerRunning = false; // Biến cờ kiểm soát trạng thái Web Server nội bộ

// ====================== BỘ LỌC TÍN HIỆU KALMAN ======================
class SimpleKalmanFilter {
  public:
    SimpleKalmanFilter(float mea_e, float est_e, float q) { _err_measure = mea_e; _err_estimate = est_e; _q = q; }
    float updateEstimate(float mea) {
      float _kalman_gain = _err_estimate / (_err_estimate + _err_measure);
      float _current_estimate = _last_estimate + _kalman_gain * (mea - _last_estimate);
      _err_estimate = (1.0 - _kalman_gain) * _err_estimate + fabs(_last_estimate - _current_estimate) * _q;
      _last_estimate = _current_estimate;
      return _current_estimate;
    }
  private:
    float _err_measure, _err_estimate, _q, _last_estimate = 0;
};
SimpleKalmanFilter tempK(0.4, 0.4, 0.02), humK(1.0, 1.0, 0.03);

// ====================== BỘ LỌC TRUNG VỊ (MEDIAN FILTER) ======================
template<int SIZE>
class MedianFilter {
  public:
    float update(float input) {
      if (!_initialized) {
        for (int i = 0; i < SIZE; i++) _buffer[i] = input;
        _initialized = true;
      }
      _buffer[_index] = input;
      _index = (_index + 1) % SIZE;
      float temp[SIZE];
      for (int i = 0; i < SIZE; i++) temp[i] = _buffer[i];
      for (int i = 0; i < SIZE - 1; i++) {
        for (int j = i + 1; j < SIZE; j++) {
          if (temp[j] < temp[i]) {
            float t = temp[i];
            temp[i] = temp[j]; temp[j] = t;
          }
        }
      }
      return temp[SIZE / 2];
    }
  private:
    float _buffer[SIZE] = {0};
    int _index = 0;
    bool _initialized = false;
};
MedianFilter<5> pm25Median; MedianFilter<5> pm10Median; MedianFilter<5> pm1Median;
MedianFilter<5> tvocMedian; MedianFilter<5> eco2Median;

// ====================== BỘ LỌC EMA THÍCH NGHỊ (ADAPTIVE EMA) ======================
class AdaptiveEMA {
  public:
    AdaptiveEMA(float slowAlpha, float fastAlpha, float threshold) {
      _slowAlpha = slowAlpha; _fastAlpha = fastAlpha; _threshold = threshold;
    }
    float update(float input) {
      if (!_initialized) { _last = input; _initialized = true; return _last; }
      float diff = fabs(input - _last);
      float alpha = (diff > _threshold) ? _fastAlpha : _slowAlpha;
      _last = alpha * input + (1.0f - alpha) * _last;
      return _last;
    }
  private:
    float _slowAlpha, _fastAlpha, _threshold, _last = 0; bool _initialized = false;
};
AdaptiveEMA pm25EMA(0.08, 0.35, 12.0); AdaptiveEMA pm10EMA(0.08, 0.35, 15.0);
AdaptiveEMA pm1EMA (0.08, 0.35, 10.0);  AdaptiveEMA co2EMA (0.05, 0.25, 80.0);
AdaptiveEMA tvocEMA(0.02, 0.18, 80.0); AdaptiveEMA eco2EMA(0.03, 0.20, 100.0);

// ====================== SLEW RATE LIMITER CHO TFT UI ======================
class SlewRateLimiter {
  public:
    SlewRateLimiter(float maxStepPerSec) { _maxStep = maxStepPerSec; }
    float update(float target, float deltaSec) {
      if (!_initialized) { _current = target; _initialized = true; return _current; }
      float diff = target - _current;
      float step = _maxStep * deltaSec;
      if (fabs(diff) > step) { _current += (diff > 0) ? step : -step; } 
      else { _current = target; }
      return _current;
    }
  private:
    float _current = 0; float _maxStep; bool _initialized = false;
};
SlewRateLimiter co2Display(50.0); SlewRateLimiter pm25Display(2.0);

// ================= BITMAPS ĐỒ HỌA MÀN HÌNH =================
const unsigned char epd_bitmap_network_4_bars [] PROGMEM = { 0x00, 0x0e, 0x00, 0x0e, 0x00, 0x0e, 0x00, 0x0e, 0x00, 0xee, 0x00, 0xee, 0x00, 0xee, 0x00, 0xee, 0x0e, 0xee, 0x0e, 0xee, 0x0e, 0xee, 0x0e, 0xee, 0xee, 0xee, 0xee, 0xee, 0xee, 0xee, 0x00, 0x00 };
const unsigned char epd_bitmap_wifi_not_connected [] PROGMEM = { 0x21, 0xf0, 0x00, 0x16, 0x0c, 0x00, 0x08, 0x03, 0x00, 0x25, 0xf0, 0x80, 0x42, 0x0c, 0x40, 0x89, 0x02, 0x20, 0x10, 0xa1, 0x00, 0x23, 0x58, 0x80, 0x04, 0x24, 0x00, 0x08, 0x52, 0x00, 0x01, 0xa8, 0x00, 0x02, 0x04, 0x00, 0x00, 0x42, 0x00, 0x00, 0xa1, 0x00, 0x00, 0x40, 0x80, 0x00, 0x00, 0x00 };
const unsigned char epd_bitmap_network_www [] PROGMEM = { 0x03, 0xc0, 0x0d, 0xb0, 0x32, 0x4c, 0x24, 0x24, 0x44, 0x22, 0x7f, 0xfe, 0x88, 0x11, 0x88, 0x11, 0x88, 0x11, 0x88, 0x11, 0x7f, 0xfe, 0x44, 0x22, 0x24, 0x24, 0x32, 0x4c, 0x0d, 0xb0, 0x03, 0xc0 };
const unsigned char epd_bitmap_wifi [] PROGMEM = { 0x01, 0xf0, 0x00, 0x06, 0x0c, 0x00, 0x18, 0x03, 0x00, 0x21, 0xf0, 0x80, 0x46, 0x0c, 0x40, 0x88, 0x02, 0x20, 0x10, 0xe1, 0x00, 0x23, 0x18, 0x80, 0x04, 0x04, 0x00, 0x08, 0x42, 0x00, 0x01, 0xb0, 0x00, 0x02, 0x08, 0x00, 0x00, 0x40, 0x00, 0x00, 0xa0, 0x00, 0x00, 0x40, 0x00, 0x00, 0x00, 0x00 };
const unsigned char epd_bitmap_weather_temperature [] PROGMEM = { 0x03, 0xf0, 0x00, 0x00, 0x03, 0xf0, 0x00, 0x00, 0x0c, 0x0c, 0x00, 0x0c, 0x0c, 0x0c, 0x00, 0x0c, 0x0c, 0xcf, 0x00, 0x33, 0x0c, 0xcf, 0x00, 0x33, 0x0c, 0xcc, 0x00, 0x0c, 0x0c, 0xcc, 0x00, 0x0c, 0x0c, 0xcf, 0x0f, 0xc0, 0x0c, 0xcf, 0x0f, 0xc0, 0x0c, 0xcc, 0x3c, 0x00, 0x0c, 0xcc, 0x3c, 0x00, 0x0c, 0xcf, 0x30, 0x00, 0x0c, 0xcf, 0x30, 0x00, 0x0c, 0xcc, 0x30, 0x00, 0x0c, 0xcc, 0x30, 0x00, 0x0c, 0xcc, 0x3c, 0x00, 0x0c, 0xcc, 0x3c, 0x00, 0x30, 0xc3, 0x0f, 0xc0, 0x30, 0xc3, 0x0f, 0xc0, 0xc3, 0xf0, 0xc0, 0x00, 0xc3, 0xf0, 0xc0, 0x00, 0xcc, 0xfc, 0xc0, 0x00, 0xcc, 0xfc, 0xc0, 0x00, 0xcf, 0xfc, 0xc0, 0x00, 0xcf, 0xfc, 0xc0, 0x00, 0xc3, 0xf0, 0xc0, 0x00, 0xc3, 0xf0, 0xc0, 0x00, 0x30, 0x03, 0x00, 0x00, 0x30, 0x03, 0x00, 0x00, 0x0f, 0xfc, 0x00, 0x00, 0x0f, 0xfc, 0x00, 0x00 };
const unsigned char epd_bitmap_weather_humidity [] PROGMEM = { 0x00, 0x30, 0x00, 0x00, 0x30, 0x00, 0x00, 0x30, 0x00, 0x00, 0x30, 0x00, 0x00, 0xf0, 0x00, 0x00, 0xf0, 0x00, 0x00, 0xfc, 0x00, 0x00, 0xfc, 0x00, 0x03, 0xfc, 0x00, 0x03, 0xfc, 0x00, 0x03, 0xff, 0x00, 0x03, 0xff, 0x00, 0x0f, 0xff, 0xc0, 0x0f, 0xff, 0xc0, 0x0f, 0xff, 0xc0, 0x0f, 0xff, 0xc0, 0x3f, 0xfc, 0xf0, 0x3f, 0xfc, 0xf0, 0x3f, 0xff, 0x30, 0x3f, 0xff, 0x30, 0xff, 0xff, 0x3c, 0xff, 0xff, 0x3c, 0xff, 0xff, 0xfc, 0xff, 0xff, 0xfc, 0x3f, 0xff, 0xf0, 0x3f, 0xff, 0xf0, 0x3f, 0xff, 0xf0, 0x3f, 0xff, 0xf0, 0x0f, 0xff, 0xc0, 0x0f, 0xff, 0xc0, 0x00, 0xff, 0x00, 0x00, 0xff, 0x00 };

// ================= BIẾN CHIA SẺ VÀ CƠ CHẾ ĐỒNG BỘ FREERTOS =================
struct SharedData {
  float    sh_temp = 0.0; float    sh_hum = 0.0;
  uint16_t sh_pm25 = 0;   uint16_t sh_pm10 = 0;
  int      sh_aqi = 0;    int      sh_pm1 = 0;
  int      sh_co2 = 0;     int      sh_eco2 = 0; int      sh_tvoc = 0;
  bool     sh_isPushSuccess = false; bool     sh_isConnected = false;
  bool     sh_pmsStatus = false;     bool     sh_scdStatus = false; bool     sh_ccsStatus = false;
  bool     sh_portalRunning = false; bool     sh_otaRunning = false;    
  bool     sh_mustRedraw = false; 
};
SharedData shared; 
uint8_t pmsBuffer[32]; 

SemaphoreHandle_t xMutex = NULL; TaskHandle_t xTaskTFTHandle = NULL; TaskHandle_t portalTaskHandle = NULL;

unsigned long lastBuzzerToggle = 0; bool buzzerState = false; unsigned long bootTime = 0; uint8_t httpFailCount = 0;
unsigned long lastButtonChange = 0; bool lastButtonState = HIGH; bool stableButtonState = HIGH; unsigned long pressStart = 0; bool buttonHolding = false;

// ====================== CÁC HÀM TRỢ GIÚP ĐỒ HỌA MÀN HÌNH VÀ TÍNH TOÁN ======================
void drawStringCenter(const char* text, int x_box, int y_baseline, int w_box) {
  int16_t x1, y1; uint16_t w, h;
  tft->getTextBounds(text, 0, 0, &x1, &y1, &w, &h);
  tft->setCursor(x_box + (w_box - w) / 2, y_baseline); tft->print(text);
}

uint16_t getAQIColor(int val) {
  if (val <= 50)  return 0x07E0;  if (val <= 100) return 0xFFE0;
  if (val <= 150) return 0xFBE0;  if (val <= 200) return 0xF800; 
  if (val <= 300) return 0x89ED;  return 0x7804;
}

void checkAlertsNonBlocking(int aqi, float pm25, int co2, float temp, bool isPortalActive) {
  static unsigned long cycleStart = 0;
  static bool lastCritical = false;
  if (isPortalActive || shared.sh_otaRunning) { digitalWrite(BUZZER_PIN, LOW); return; }
  bool isCritical = (aqi > 150) || (pm25 > 65) || (co2 > 1500) || (temp > 38.0);
  if (isCritical){
        unsigned long currentMillis = millis();
        if (!lastCritical) {
            cycleStart = currentMillis; lastCritical = true;
        } if (currentMillis - cycleStart > 13000) {
            cycleStart = currentMillis;
        }
        unsigned long t = currentMillis - cycleStart;
        if ((t < 300) || (t > 600 && t < 900) || (t > 1200 && t < 1500)) {
            digitalWrite(BUZZER_PIN, HIGH);
        } else {
            digitalWrite(BUZZER_PIN, LOW);
        }
    } else { digitalWrite(BUZZER_PIN, LOW); buzzerState = false; }
}

bool readPMS() {
  if (Serial2.available() < 32) return false;
  if (Serial2.peek() != 0x42) { Serial2.read(); return false; }
  uint8_t frame[32];
  if (Serial2.read() != 0x42) return false; if (Serial2.read() != 0x4D) return false;
  frame[0] = 0x42; frame[1] = 0x4D;
  if (Serial2.readBytes(&frame[2], 30) != 30) return false;
  uint16_t sum = 0;
  for (int i = 0; i < 30; i++) sum += frame[i];
  uint16_t checksum = ((uint16_t)frame[30] << 8) | frame[31];
  if (sum != checksum) return false;
  memcpy(pmsBuffer, frame, 32); return true;
}

// ====================== US EPA AQI (PM2.5 ONLY) ======================
int calcAQI_PM25_US(float pm25) {
    float Clow, Chigh;
    int Ilow, Ihigh;
    if (pm25 < 0) return 0;
    if (pm25 <= 12.0) { Clow = 0.0;   Chigh = 12.0;   Ilow = 0;     Ihigh = 50;
    } else if (pm25 <= 35.4) { Clow = 12.1;  Chigh = 35.4; Ilow = 51;    Ihigh = 100;
    } else if (pm25 <= 55.4) { Clow = 35.5;  Chigh = 55.4; Ilow = 101;   Ihigh = 150;
    } else if (pm25 <= 150.4) {  Clow = 55.5;  Chigh = 150.4; Ilow = 151;   Ihigh = 200;
    } else if (pm25 <= 250.4) { Clow = 150.5; Chigh = 250.4;  Ilow = 201;   Ihigh = 300;
    } else if (pm25 <= 350.4) {  Clow = 250.5; Chigh = 350.4;  Ilow = 301;   Ihigh = 400;
    } else if (pm25 <= 500.4) {  Clow = 350.5; Chigh = 500.4;  Ilow = 401;   Ihigh = 500;
    } else { return 500;
    }
    return round(
        ((float)(Ihigh - Ilow) / (Chigh - Clow)) * (pm25 - Clow) + Ilow
    );
}

void drawInterfaceStatic() {
  tft->fillScreen(0x0000); tft->setFont(&FreeSans9pt7b); tft->setTextColor(0xFFFF);
  tft->drawLine(196, 0, 196, 116, 0xFFFF); tft->drawLine(197, 116, 280, 116, 0xFFFF);
  tft->drawLine(196, 121, 196, 239, 0xFFFF); tft->drawLine(196, 121, 279, 121, 0xFFFF);
  tft->drawLine(84, 122, 84, 240, 0xFFFF); tft->drawLine(83, 122, 0, 122, 0xFFFF);
  tft->drawLine(84, 116, 84, 0, 0xFFFF); tft->drawLine(83, 116, 0, 116, 0xFFFF);
  tft->drawLine(87, 141, 191, 141, 0xFFFF); tft->drawLine(87, 141, 87, 240, 0xFFFF);
  tft->drawLine(192, 141, 192, 239, 0xFFFF); tft->drawLine(87, 116, 87, 0, 0xFFFF);
  tft->drawLine(88, 116, 192, 116, 0xFFFF); tft->drawLine(192, 116, 192, 0, 0xFFFF);
  tft->drawBitmap(203, 5, epd_bitmap_weather_temperature, 32, 32, 0x7F2);
  tft->drawBitmap(202, 131, epd_bitmap_weather_humidity, 22, 32, 0x7F2);
  tft->setTextSize(1); tft->setCursor(15, 25);  tft->print("PM2.5");
  tft->setCursor(15, 145); tft->print("TVOC"); tft->setCursor(254, 100);tft->print("C");
  tft->setCursor(254, 225);tft->print("%"); tft->drawCircle(248, 88, 2, 0xFFFF);
}

// ====================== CẬP NHẬT GIÁ TRỊ LÊN MÀN HÌNH TFT CỦA THIẾT BỊ ======================
void updateTFTValues(int local_aqi, int local_tvoc, int local_co2, float local_pm25, 
                     float local_temp, float local_hum, bool local_push, bool local_wifi,
                     bool pmsOk, bool scdOk, bool ccsOk, bool localPortalRunning, float deltaSec, bool mustRedraw) {
  tft->setFont(&FreeSans9pt7b);
  static int lastAQI = -1; static float lastPM25 = -1; static int lastCO2 = -1; static int lastTVOC = -1;
  static float lastTemp = -1.0; static float lastHum = -1.0; static bool lastPmsOk = true;
  static bool lastScdOkCO2  = true; static bool lastScdOkTemp = true; static bool lastScdOkHum  = true;
  static bool lastCcsOk = true; static bool lastPush = false; static bool lastWifi = false; static bool lastOtaRunning = false;
  char buf[16];

  if (mustRedraw) {
    drawInterfaceStatic(); 
    lastAQI = -1; lastPM25 = -1.0; lastCO2 = -1; lastTVOC = -1;
    lastTemp = -1.0; lastHum = -1.0;
    lastPush = !local_push; lastWifi = !local_wifi; 
  }

  int displayCO2  = (int)co2Display.update(local_co2, deltaSec);
  int displayPM25 = (int)pm25Display.update(local_pm25, deltaSec);

  if (shared.sh_otaRunning) {
    if (!lastOtaRunning) {
      tft->fillRect(88, 1, 104, 115, 0xF800); tft->setTextColor(0xFFFF); tft->setTextSize(1);
      drawStringCenter("OTA", 88, 45, 104); drawStringCenter("UPGRADE", 88, 85, 104);
      lastOtaRunning = true;
    }
    return; 
  }
  lastOtaRunning = false;

  if (localPortalRunning) {
    tft->fillRect(88, 1, 104, 115, 0x001F); tft->setTextColor(0xFFFF); tft->setTextSize(1);
    drawStringCenter("WIFI", 88, 45, 104); drawStringCenter("CONFIG", 88, 85, 104); 
    lastAQI = -1; 
  } else if (local_aqi != lastAQI || pmsOk != lastPmsOk) {
    uint16_t aqiColor = pmsOk ? getAQIColor(local_aqi) : 0xF800; 
    tft->fillRect(88, 1, 104, 115, aqiColor); tft->setTextColor(aqiColor == 0xFFE0 ? 0x0000 : 0xFFFF);
    tft->setTextSize(2); drawStringCenter("AQI", 88, 35, 104); tft->setTextSize(pmsOk ? 3 : 2);
    drawStringCenter(pmsOk ? itoa(local_aqi, buf, 10) : "ERR", 88, 95, 104); 
    lastAQI = local_aqi; lastPmsOk = pmsOk;
  }

  if (local_push != lastPush || local_wifi != lastWifi) {
    tft->fillRect(85, 117, 106, 23, 0x0000);
    if (local_push) tft->drawBitmap(115, 122, epd_bitmap_network_4_bars, 15, 16, 0x07E0);
    else tft->drawBitmap(90, 122, epd_bitmap_network_www, 16, 16, 0xFFFF);
    tft->drawBitmap(local_wifi ? 170 : 145, 122, local_wifi ? epd_bitmap_wifi : epd_bitmap_wifi_not_connected, 19, 16, local_wifi ? 0x07E0 : 0xF800);
    lastPush = local_push; lastWifi = local_wifi;
  }

  if (displayCO2 != lastCO2 || scdOk != lastScdOkCO2) {
    tft->fillRect(95, 170, 90, 40, 0x0000); tft->setTextColor(0xFFFF); tft->setTextSize(1); drawStringCenter("CO2", 87, 160, 105);   
    if (scdOk) {
      uint16_t co2Color = (displayCO2 <= 800 ? 0x0720 : (displayCO2 <= 1200 ? 0xFFE0 : (displayCO2 <= 2000 ? 0xFBE0 : 0xF800)));
      tft->setTextColor(co2Color); tft->setTextSize(2); itoa(displayCO2, buf, 10);
    } else { tft->setTextColor(0x7BEF); tft->setTextSize(2); strcpy(buf, "ERR"); }
    drawStringCenter(buf, 87, 200, 105); tft->setTextSize(1); tft->setTextColor(0xFFFF); drawStringCenter("ppm", 87, 225, 105); 
    lastCO2 = displayCO2; lastScdOkCO2 = scdOk;
  }

  if (displayPM25 != (int)lastPM25 || pmsOk != lastPmsOk) {
    tft->fillRect(5, 40, 75, 40, 0x0000);
    if (pmsOk) {
      uint16_t pmColor = (displayPM25 <= 12 ? 0x0720 : (displayPM25 <= 35 ? 0xFFE0 : (displayPM25 <= 55 ? 0xFBE0 : (displayPM25 <= 150 ? 0xF800 : (displayPM25 <= 250 ? 0x89ED : 0x7804)))));
      tft->setTextColor(pmColor); tft->setTextSize(2); itoa(displayPM25, buf, 10);
    } else { tft->setTextColor(0x7BEF); tft->setTextSize(2); strcpy(buf, "ERR"); }
    drawStringCenter(buf, 0, 75, 84); tft->setTextSize(1); tft->setTextColor(0xFFFF); drawStringCenter("ug/m3", 0, 105, 84); 
    lastPM25 = displayPM25;
  }

  if (local_tvoc != lastTVOC || ccsOk != lastCcsOk) {
    tft->fillRect(-1, 160, 85, 40, 0x0000);
    if (ccsOk) {
      uint16_t tvocColor = (local_tvoc <= 300 ? 0x0720 : (local_tvoc <= 500 ? 0xFFE0 : (local_tvoc <= 1000 ? 0xFBE0 : (local_tvoc <= 3000 ? 0xF800 : 0x89ED))));
      tft->setTextColor(tvocColor); tft->setTextSize(2); itoa(local_tvoc, buf, 10);
    } else { tft->setTextColor(0x7BEF); tft->setTextSize(2); strcpy(buf, "ERR"); }
    drawStringCenter(buf, -3, 195, 84); tft->setTextSize(1); tft->setTextColor(0xFFFF); drawStringCenter("ppb", 0, 225, 84); 
    lastTVOC = local_tvoc; lastCcsOk = ccsOk;
  }

  if (abs(local_temp - lastTemp) >= 0.1 || scdOk != lastScdOkTemp) {
    tft->fillRect(198, 45, 82, 35, 0x0000);
    if (scdOk) {
      uint16_t tempColor = (local_temp <= 16.0 ? 0x07E0 : (local_temp <= 20.0 ? 0x92BF : (local_temp <= 25.0 ? 0x0720 : (local_temp <= 30.0 ? 0xFFE0 : (local_temp <= 35.0 ? 0xFBE0 : 0xF800)))));
      tft->setTextColor(tempColor); tft->setTextSize(2); dtostrf(local_temp, 1, 1, buf);
    } else { tft->setTextColor(0x7BEF); tft->setTextSize(2); strcpy(buf, "ERR"); }
    drawStringCenter(buf, 196, 75, 84); lastTemp = local_temp; lastScdOkTemp = scdOk;
  }

  if (abs((int)local_hum - (int)lastHum) >= 1 || scdOk != lastScdOkHum) {
    tft->fillRect(198, 166, 82, 35, 0x0000);
    if (scdOk) {
      uint16_t humColor = (local_hum <= 25 ? 0xFE4C : (local_hum <= 40 ? 0xFFE0 : (local_hum <= 60 ? 0x0720 : (local_hum <= 75 ? 0x665F : 0x53DF))));
      tft->setTextColor(humColor); tft->setTextSize(2); itoa((int)local_hum, buf, 10);
    } else { tft->setTextColor(0x7BEF); tft->setTextSize(2); strcpy(buf, "ERR"); }
    drawStringCenter(buf, 196, 195, 84); lastHum = local_hum; lastScdOkHum = scdOk;
  }
}

void saveWifiCallback(){
    String newRoom = custom_room.getValue();
    if (newRoom.length() > 0) {  prefs.putString("room_id", newRoom); newRoom.toCharArray(roomId, sizeof(roomId));
    }
    String newRoomName = custom_room_name.getValue();
    if (newRoomName.length() > 0){  prefs.putString( "room_name", newRoomName); newRoomName.toCharArray( roomName, sizeof(roomName));
    }
    tft->fillRect(88,1,104,115,0x0400); drawStringCenter("SAVED",88,45,104); delay(1500); ESP.restart();
}

void onOTAStart() { shared.sh_otaRunning = true; digitalWrite(BUZZER_PIN, LOW); }
void onOTAEnd(bool success) { shared.sh_otaRunning = false; }

// ====================== PORTAL CONFIG TASK (ĐƯỢC GỌI KHI NHẤN GIỮ NÚT) ======================
void PortalTask(void *pvParameters) {
  if (xSemaphoreTake(xMutex, portMAX_DELAY) == pdTRUE) { 
    shared.sh_portalRunning = true; 
    xSemaphoreGive(xMutex); 
  }
  digitalWrite(BUZZER_PIN, LOW); 
  
  // Tắt hoàn toàn Web Server nội bộ để giải phóng bộ nhớ và tránh lỗi tranh chấp cổng mạng (Port 80)
  server.stop(); 
  isServerRunning = false;
  WiFi.mode(WIFI_AP_STA);
  
  // Kích hoạt chế độ giao diện tối hệ thống cho TẤT CẢ các trang con (/wifi, /info)
  wm.setDarkMode(true);
  wm.setClass("invert"); 

  // Cấu hình các tham số cơ bản cho WiFiManager
  wm.setSaveConfigCallback(saveWifiCallback); 
  wm.setConfigPortalTimeout(90); 
  wm.setConnectTimeout(20); 
  wm.setBreakAfterConfig(true); 
  wm.setShowInfoErase(false); 
  wm.setShowInfoUpdate(false); 
  
  // Cấu hình Menu: Giữ cấu hình (wifi), thông tin (info), thoát (exit). Bỏ hoàn toàn Update.
    const char* menu[] = {"wifi", "info", "update", "exit"};
  wm.setMenu(menu, 4);

  // Ép CSS bao phủ toàn cục - Giữ nguyên vạch sóng chuẩn vị trí bên phải
  wm.setCustomHeadElement(R"rawliteral(
<style>
body, body.invert{background:#18191A!important;color:#E4E6EB!important;font-family:sans-serif!important;}
.wrap, body.invert .wrap{background:#242526!important;max-width:420px!important;padding:35px 25px!important;border-radius:16px!important;box-shadow:0 12px 40px rgba(0,0,0,.5)!important;border:none!important;}

/* Triệt tiêu hoàn toàn các ô nền đen tương phản */
body.invert div, body.invert p, body.invert label, body.invert h1, body.invert h3, body.invert a {
  background: transparent !important;
  background-color: transparent !important;
  color:#E4E6EB!important;
}

/* Định dạng cụm tiêu đề chính của trạm giám sát IAQ SYSTEM */
h1{font-size:0!important;padding:0!important;margin:0 0 25px 0!important;text-align:center!important;}
h1::before{content:'IAQ MONITOR SYSTEM'!important;display:block!important;color:#F5F6F7!important;font-size:24px!important;font-weight:700!important;letter-spacing:1px!important;line-height:1.2!important;}
h1::after{content:'Hệ thống giám sát chất lượng không khí'!important;display:block!important;color:#90949C!important;font-size:13px!important;font-weight:normal!important;margin-top:6px!important;}
h3{display:none!important;}

/* ===== WIFI LIST ===== */

.wrap > div > div{
    display:flex !important;
    align-items:center !important;
}

.wrap div[role='img']{
    order:1 !important;
    width:24px !important;
    margin-right:12px !important;
    position:static !important;
}

.wrap a[href^='#p']{
    order:2 !important;
    flex:1 !important;
}

.wrap div.h{
    order:3 !important;
    width:50px !important;
    text-align:right !important;
    position:static !important;
}
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
void loop() { 
  vTaskDelete(NULL); 
}
